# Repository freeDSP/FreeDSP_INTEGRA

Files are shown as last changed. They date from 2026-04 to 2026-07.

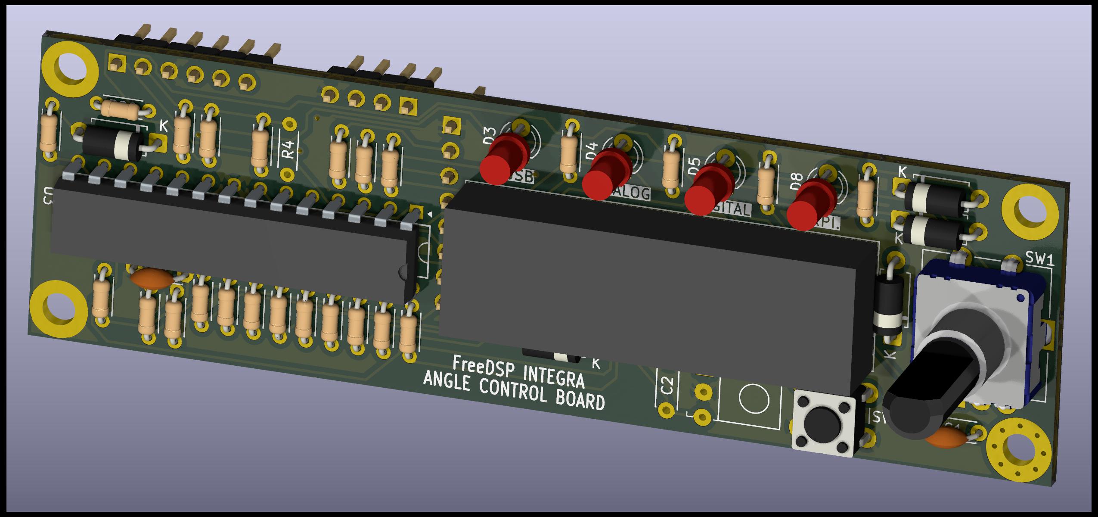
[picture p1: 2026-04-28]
KiCAD_Files/FreeDSP_INTEGRA_PANELBOARD/Picture/FreeDSP_INTEGRA_PANEL_PCB_Front.jpg

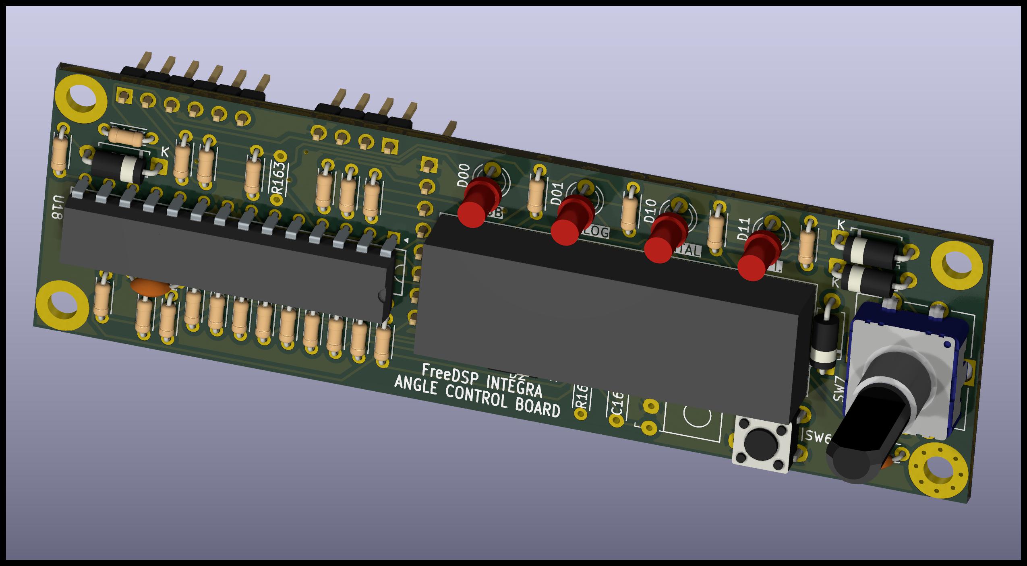
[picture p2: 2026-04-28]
KiCAD_Files/FreeDSP_INTEGRA_PANELBOARD/Picture/FreeDSP_INTEGRA_PANEL_PCB_Parse.jpg

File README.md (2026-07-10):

# FreeDSP_INTEGRA

An integrated four-channel 2.1MHz switching Class-D Amplifier embedded with an ADAU1466/1452 DSP processor.

Details are stated in the [wiki page](https://github.com/freeDSP/FreeDSP_INTEGRA/wiki)  

Project [Web page (Japanese)](https://cyberpithilo.web.fc2.com/audio/FreeDSP_INTEGRA/index.html)
  
DIY Audio [Forum Thread](https://www.diyaudio.com/community/threads/freedsp-integra.420623) 

# Variations  
## INTEGRA-QUAD BALANCED XLR INPUT VERSION 
INTEGRA_XLR

## INTEGRA-QUAD Differential RCA-PIN INPUT VERSION
INTEGRA_RCA

## Features:

BoardDiscription  

            Double Differential High-Performance ADC Input Circuit
            Balanced-XLR Input  or Differential RCA-pin Analog Input
            Optical or Coaxial S/PDIF Input
            Amanero Combo384/YORK pico or XIAO RP2040 USB-Audio Input
            Raspberry-pi ZERO 2W Slot with control buttons
            TL-232R-3V3 USB-UART Cable Connection Pin-Header for Raspberry-pi
            AUX-ADC pin header
            Onboard two AUX-ADC Trimmer-POTs
            Optional Toggle Switch for DSP control
            External Front Panel Control PCB connectivity
            DC24V Single Power Supply

# Block Diagram
  SystemBlockDiagram

# Optional Board  
Front Panel Extension Board  


# Audio Performance 
ADC Distortion Performance  

594204503-1d5c8a78-7449-4203-bfe5-b2860b34c397

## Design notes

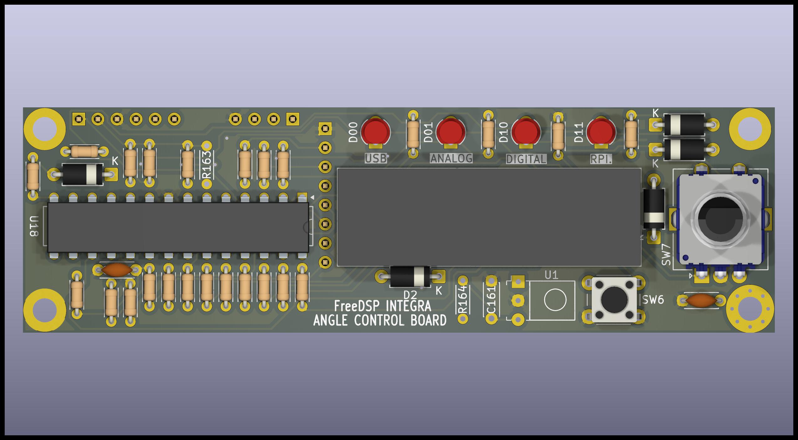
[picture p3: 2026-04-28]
KiCAD_Files/FreeDSP_INTEGRA_PANELBOARD/Picture/FreeDSP_INTEGRA_PANEL_PCB.jpg

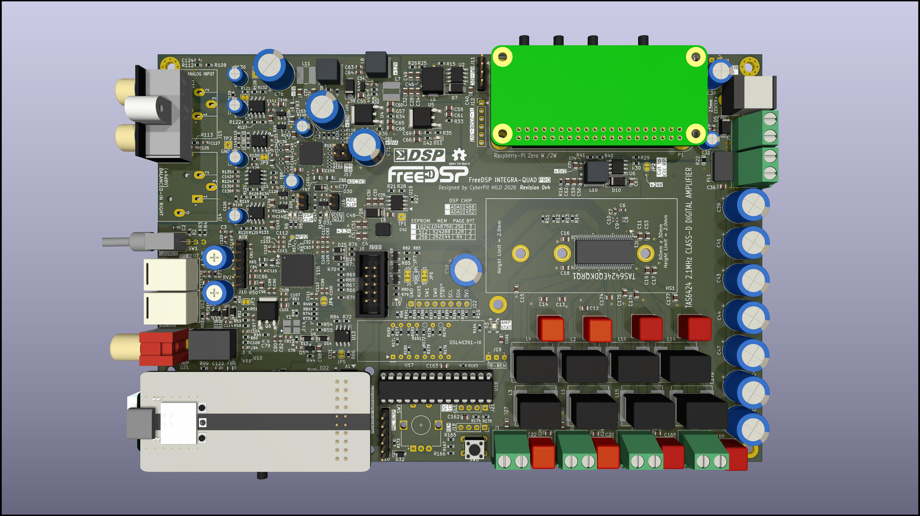
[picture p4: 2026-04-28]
KiCAD_Files/FreeDSP_INTEGRA_QUAD-PRO/Picture/FreeDSP_INTEGRA_QUAD-PRO_TopView.jpg

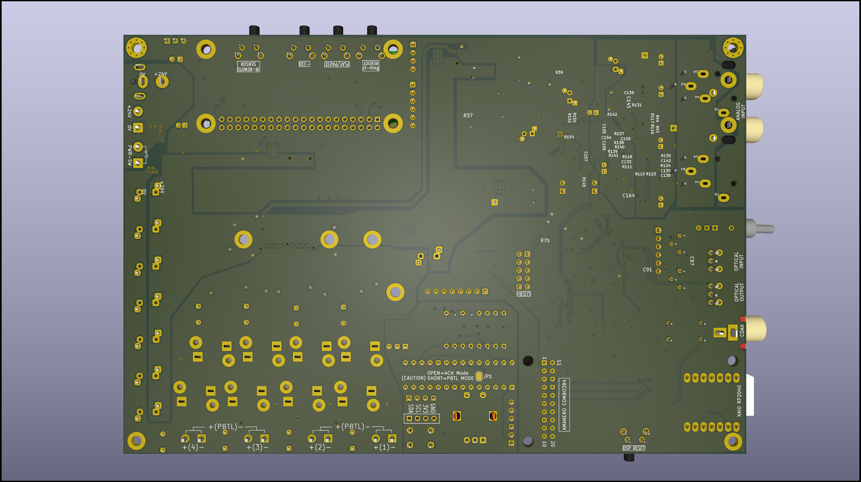
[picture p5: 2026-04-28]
KiCAD_Files/FreeDSP_INTEGRA_QUAD-PRO/Picture/FreeDSP_INTEGRA_QUAD_Bottom.jpg

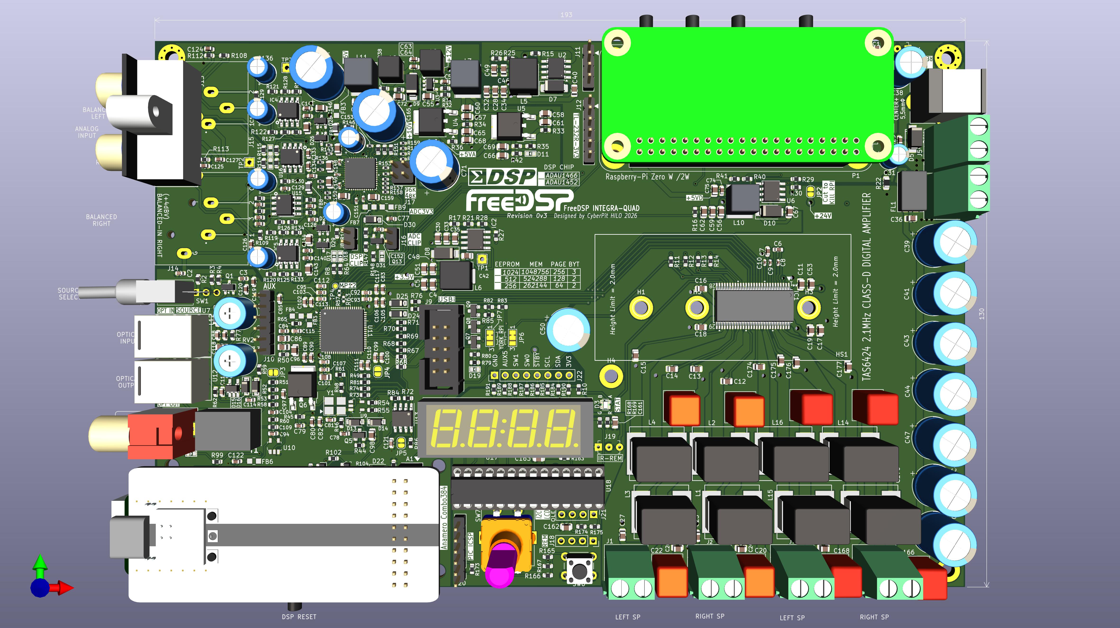
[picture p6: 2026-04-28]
KiCAD_Files/FreeDSP_INTEGRA_QUAD-PRO/Picture/FreeDSP_INTEGRA_QUAD-PRO.jpg

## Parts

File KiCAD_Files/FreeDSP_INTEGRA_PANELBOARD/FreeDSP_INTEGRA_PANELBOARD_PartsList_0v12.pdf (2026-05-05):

## FreeUSB INTEGRA Panel Board Bill of Materials

Reference | Value | JLPCB# | Footprint | Datasheet
C1 | 0.1uF/50V | HAND | Capacitor_THT:C_Disc_D4.3mm_W1.9mm_P5.00mm | MLCC 5mm pitch
C2 | 0.1uF/50V | HAND | Capacitor_THT:C_Disc_D4.3mm_W1.9mm_P5.00mm | MLCC 5mm pitch
C3 | 0.1uF/50V | HAND | Capacitor_THT:C_Disc_D4.3mm_W1.9mm_P5.00mm | MLCC 5mm pitch
C4 | 10uF/25V | NOP | Capacitor_SMD:C_0805_2012Metric | -
D1,D2,D6,D7,D9 | BAT43 1S4 | HAND | Diode_THT:D_A-405_P7.62mm_Horizontal | https://akizukidenshi.com/catalog/g/g113907/https://akizukidenshi.com/catalog/g/g116384/
D3,D4,D5,D8 | LED_YELLOW | | LED_THT:LED_D3.0mm_FlatTop | https://akizukidenshi.com/catalog/g/g111639/
HM1 | MountingHole_Pad_via | - | MountingHole:MountingHole_3.2mm_M3_ISO7380_Pad_TopBottom | ~
J1 | Conn_01x04 | NOP | Connector_PinHeader_2.54mm:PinHeader_1x04_P2.54mm_Vertical | https://akizukidenshi.com/catalog/g/g100167/
J2 | Header_01x06 | HAND | Connector_PinHeader_2.54mm:PinHeader_1x06_P2.54mm_Vertical
J3 | Conn_01x08 | HAND | Connector_PinHeader_2.54mm:PinHeader_1x08_P2.54mm_Vertical
MH1,MH2 | MountingHole | - | MountingHole:MountingHole_3.2mm_M3_DIN965_Pad_TopBottom | M3 Screw & 10mm Spacer
MH3 | M3 | - | MountingHole:MountingHole_3.2mm_M3_Pad_Via | M3 Screw & 10mm Spacer
R1,R8 | 1k | HAND | Resistor_THT:R_Axial_DIN0204_L3.6mm_D1.6mm_P5.08mm_Horizontal | Through-hole Lead Type Carbon Resistor 1/6W (5mm pitch)
R2,R3 | 470R | HAND | Resistor_THT:R_Axial_DIN0204_L3.6mm_D1.6mm_P5.08mm_Horizontal | Through-hole Lead Type Carbon Resistor 1/6W (5mm pitch)
R4 | 22k | NOP | Resistor_THT:R_Axial_DIN0204_L3.6mm_D1.6mm_P5.08mm_Horizontal | Through-hole Lead Type Carbon Resistor 1/6W (5mm pitch)
R5,R6,R7,R19,R20,R21 | 10k | HAND | Resistor_THT:R_Axial_DIN0204_L3.6mm_D1.6mm_P5.08mm_Horizontal | Through-hole Lead Type Carbon Resistor 1/6W (5mm pitch)
R9,R10,R11,R12,R13,R14,R15,R16,R22,R23,R24,R25 | 47R | HAND | Resistor_THT:R_Axial_DIN0204_L3.6mm_D1.6mm_P5.08mm_Horizontal | Through-hole Lead Type Carbon Resistor 1/6W (5mm pitch)
R17,R18 | 0R | HAND | Resistor_THT:R_Axial_DIN0204_L3.6mm_D1.6mm_P5.08mm_Horizontal | JUMPER
SW1 | EN11-HSB1AF15 | HAND | Myfootprints:RotaryEncoder_TT-Ele_EN11-HSB1AF15 | https://akizukidenshi.com/catalog/g/g106357/https://ja.aliexpress.com/item/1005012129021462.html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.

4d053lvQ3lvQ8i&gpsid=pcDetailTopMoreOtherSeller&scm=1007.40050.354490.0&scm_id=1007.40050.354490.0&scmurl=1007.40050.354490.0&pvid=e0b7cc45-f1b5-4d73-a206-cf6449d124c2&_t=gpsid%3ApcDetailTopMoreOtherSeller%2Cscm-url%3A1007.40050.354490.0%2Cpvid%3Ae0b7cc45-f1b5-4d73-a206-
cf6449d124c2%2Ctpp_buckets%3A668%232846%238116%232002&pdp_ext_f=%7B%22order%22%3A%2 2-
1%22%2C%22spu_best_type%22%3A%22price%22%2C%22eval%22%3A%221%22%2C%22sceneId%22 %3A%2230050%22%2C%22fromPage%22%3A%22recommend%22%7D&pdp_npi=6%40dis%21JPY%2110 09%21181%21%21%2143.04%217.75%21%402101529317777844403287573ea9cd%2112000057600170 808%21rec%21JP%21230125749%21XZ%211%210%21n_tag%3A-29919%3Bd%3A29f7f230%3Bm03_new_user%3A-29895&utparamurl=scene%3ApcDetailTopMoreOtherSeller%7Cquery_from%3A%7Cx_object_id%3A1005012129021462%7 C_p_origin_prod%3A (https://akizukidenshi.com/catalog/g/g106357/https:/ja.aliexpress.com/item/1005012129021462.html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)
SW2 | SW_PUSH | HAND | Button_Switch_THT:SW_PUSH_6mm_H4.3mm | https://akizukidenshi.com/catalog/g/g117166/
U1 | OSRB38C9AA | NOP | digikey-footprints:IR_Receiver_TSOP38238 | NOPOP, Not Supported
U2 | OSL40391-IX | HAND | Display_7Segment:LTC-4627Jx (Anode Common) | https://akizukidenshi.com/catalog/g/g109968/http://optoelectronics.liteon.com/upload/download/DS30-2001-093/LTC-4627JD.pdf
U3 | PIC16F1938-I/SP | HAND | Myfootprints:PIC16F1938-X&slash_SP_MCH(Socket) | PIC16F1938-I/SP
W1 | 8P Female-Female Cable | - | Jumper Cable | https://akizukidenshi.com/catalog/g/g115868/

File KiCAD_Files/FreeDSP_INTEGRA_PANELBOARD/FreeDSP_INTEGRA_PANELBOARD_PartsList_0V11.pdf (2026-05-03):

## FreeUSB INTEGRA Panel Board Bill of Materials

Reference | Value | JLPCB# | Footprint | Datasheet
C1 | 0.1uF/50V | C14663 | Capacitor_THT:C_Disc_D4.3mm_W1.9mm_P5.00mm | ~
C2 | 0.1uF/50V | C28233 | Capacitor_THT:C_Disc_D4.3mm_W1.9mm_P5.00mm | ~
C3 | 0.1uF/50V | C28233 | Capacitor_THT:C_Disc_D4.3mm_W1.9mm_P5.00mm | ~
C4 | 10uF/25V | C45783 | Capacitor_SMD:C_0805_2012Metric | ~
D1,D2,D6,D7,D9 | BAT43 | C81598 | Diode_THT:D_A-405_P7.62mm_Horizontal | https://akizukidenshi.com/catalog/g/g113907/
D3,D4,D5,D8 | LED_RED | | LED_THT:LED_D3.0mm_FlatTop | https://akizukidenshi.com/catalog/g/g111577/
HM1 | MountingHole_Pad_via | - | MountingHole:MountingHole_3.2mm_M3_ISO7380_Pad_TopBottom | ~
J1 | Conn_01x04 | HAND | Connector_PinHeader_2.54mm:PinHeader_1x04_P2.54mm_Vertical | https://akizukidenshi.com/catalog/g/g100167/
J2 | Header_01x06 | HAND | Connector_PinHeader_2.54mm:PinHeader_1x06_P2.54mm_Vertical
J3 | Conn_01x08 | HAND | Connector_PinHeader_2.54mm:PinHeader_1x08_P2.54mm_Vertical
MH1,MH2 | MountingHole | - | MountingHole:MountingHole_3.2mm_M3_DIN965_Pad_TopBottom | ~
MH3 | M3 | - | MountingHole:MountingHole_3.2mm_M3_Pad_Via | ~
R1,R2,R3,R8 | 390R,430R | | Resistor_THT:R_Axial_DIN0204_L3.6mm_D1.6mm_P5.08mm_Horizontal | Through-hole Lead Type Carbon Resistor 1/4W
R4 | 22k | C31850 | Resistor_THT:R_Axial_DIN0204_L3.6mm_D1.6mm_P5.08mm_Horizontal | Through-hole Lead Type Carbon Resistor 1/4W
R5,R6,R7,R19,R20,R21 | 10k | C25804 | Resistor_THT:R_Axial_DIN0204_L3.6mm_D1.6mm_P5.08mm_Horizontal | Through-hole Lead Type Carbon Resistor 1/4W
R9,R10,R11,R12,R13,R14,R15,R16 | 75R | C4275 | Resistor_THT:R_Axial_DIN0204_L3.6mm_D1.6mm_P5.08mm_Horizontal | Through-hole Lead Type Carbon Resistor 1/4W
R17,R18 | 0R | C21189 | Resistor_THT:R_Axial_DIN0204_L3.6mm_D1.6mm_P5.08mm_Horizontal | Through-hole Lead Type Carbon Resistor 1/4W
R22,R23,R24,R25 | 33R | C23140 | Resistor_THT:R_Axial_DIN0204_L3.6mm_D1.6mm_P5.08mm_Horizontal | Through-hole Lead Type Carbon Resistor 1/4W
SW1 | EN11-HSB1AF15 | HAND | Myfootprints:RotaryEncoder_TT-Ele_EN11-HSB1AF15 | https://akizukidenshi.com/catalog/g/g106357/https://ja.aliexpress.com/item/1005012129021462.html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.

2.4d053lvQ3lvQ8i&gpsid=pcDetailTopMoreOtherSeller&scm=1007.40050.354490.0&scm_id=1007.40050.354490.0&scmurl=1007.40050.354490.0&pvid=e0b7cc45-f1b5-4d73-a206-cf6449d124c2&_t=gpsid%3ApcDetailTopMoreOtherSeller%2Cscm-url%3A1007.40050.354490.0%2Cpvid%3Ae0b7cc45-f1b5-
SW2 | SW_PUSH | HAND | Button_Switch_THT:SW_PUSH_6mm_H4.3mm | https://akizukidenshi.com/catalog/g/g117166/
U1 | OSRB38C9AA | NOP | digikey-footprints:IR_Receiver_TSOP38238 | NOPOP, Not Supported
U2 | OSL40391-IX | HAND | Display_7Segment:LTC-4627Jx | http://optoelectronics.liteon.com/upload/download/DS30-2001-093/LTC-4627JD.pdfhttps://akizukidenshi.com/catalog/g/g109966/https://akizukidenshi.com/catalog/g/g109968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
U3 | PIC16F1938-I/SP | HAND | Myfootprints:PIC16F1938-X&slash_SP_MCH(Socket) | PIC16F1938-I/SP
W1 | 8P Female-Female Cable | - | Jumper Cable | https://akizukidenshi.com/catalog/g/g115868/

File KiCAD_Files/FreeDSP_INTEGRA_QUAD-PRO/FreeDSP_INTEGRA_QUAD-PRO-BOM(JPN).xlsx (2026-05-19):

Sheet: FreeDSP_INTEGRA_QUAD-PRO
Comment | Designator | Footprint | LCSC Part #（optional）
TPS5430DDAR | U2,U6,U19 | Package_SO:TI_SO-PowerPAD-8_ThermalVias | C9864
SDV1608E5R5C180NPTF | RV3,RV4 | OPL_Capacitor:C0603 | C98320
SWPA6028S560MT | L8 | Inductor_SMD:L_Taiyo-Yuden_NR-60xx_HandSoldering | C96944
10uF | C85,C87,C128,C133,C138,C142,C158 | Capacitor_SMD:C_0603_1608Metric | C96446
OPA1612AIDR | U15,U16 | Myfootprints:SOIC127P600X175-8N | C94590
OPA1632DR | IC4,IC5 | Myfootprints:SOIC127P600X175-8N | C86715
B5819W SL | D6,D13,D14,D15,D16 | Diode_SMD:D_SOD-123 | C8598
2N7002 | Q4,Q5,Q8,Q9,Q12,Q13 | Package_TO_SOT_SMD:SOT-23 | C8545
MMBT5401 | Q2,Q3 | Package_TO_SOT_SMD:SOT-23 | C8326
1N4148W | D1,D2,D4,D20,D22,D23,D24,D25,D30,D32 | Diode_SMD:D_SOD-123 | C81598
LM317AG-TN3-R | U4,U5 | Package_TO_SOT_SMD:TO-252-2 | C77880
1nF/50V(C0G) | C24,C25,C26,C27,C86,C170,C171,C172,C173 | Capacitor_SMD:C_0805_2012Metric | C76625
BAT54A | D26,D27 | Package_TO_SOT_SMD:SOT-23 | C7502690
74LVC1G86 | U8 | Package_TO_SOT_SMD:SOT-23-5_HandSoldering | C73458
ADAU1466 | U11 | Myfootprints:LFCSP-72-1EP_10x10mm_P0.5mm_EP5.3x5.3mmL_HandSolder | C654414
SWPA6045S101MT | L7,L11 | Inductor_SMD:L_Ferrocore_DLG-0504 | C60633
10nF | C54,C81 | Capacitor_SMD:C_0603_1608Metric | C57112
1uF | C8,C9,C10,C157 | Capacitor_SMD:C_0402_1005Metric | C52923
FXL1350-100-M | L1,L2,L3,L4,L13,L14,L15,L16 | MyLibrary:7G14C47 | C526017
TAS6424EQDKQRQ1 | IC1 | Myfootprints:TAS6424QDKQ56_TEX-L | C4991409
2.2pF | C109 | Resistor_SMD:R_0603_1608Metric | C46219
22uF/6.3V | C49,C51,C75,C163 | Capacitor_SMD:C_0805_2012Metric | C45783
10uF/50V | C5,C16,C19,C28,C30,C55,C56,C57,C58,C72,C73,C98,C101,C118,C159 | Capacitor_SMD:C_0805_2012Metric | C440198
74LVC1G04 | U9 | digikey-footprints:SOT-753 | C434067
75R | R176,R177,R178,R179,R180,R181,R182,R183 | Resistor_SMD:R_0603_1608Metric | C4275
33k | R16 | Resistor_SMD:R_0603_1608Metric | C4216
2.2k | R4,R8,R13,R14,R46,R64,R75,R76,R87,R90 | Resistor_SMD:R_0603_1608Metric | C4190
1.8K | R94 | Resistor_SMD:R_0603_1608Metric | C4177
2.2uF/50V | C11,C12,C13,C14,C15,C174,C175,C176,C177 | Capacitor_SMD:C_0805_2012Metric | C377773
BAT54C | D28,D29 | Package_TO_SOT_SMD:SOT-23 | C37704
SDFL2012T220KTF | L12 | Inductor_SMD:L_0805_2012Metric_Pad1.05x1.20mm_HandSolder | C32375
22k | R23,R163 | Resistor_SMD:R_0603_1608Metric | C31850
0.1uF | C151,C154,C155,C156 | Capacitor_SMD:C_0402_1005Metric | C307331
74LVC1G04M5/TR | U10 | digikey-footprints:SOT-753 | C3007927
MACM9070-701 | FL1 | Myfootprints:ACM9070 | C2981417
1uF/50V | C32,C33,C59,C68,C69 | Capacitor_SMD:C_0805_2012Metric | C28323
OT322524.576MJBA4S | Y1 | Crystals:Crystal_SMD_TXC_7M-4pin_3.2x2.5mm_HandSoldering | C2831388
0.1uF/100V | C4,C17,C18,C34,C35,C36,C40,C42,C46,C48,C53,C60,C61,C62,C65,C66,C67,C161,C162 | Capacitor_SMD:C_0805_2012Metric | C28233
AK5574EN | IC3 | QFN48_AKM | C2651665
LED_ABGR | D3 | MyLED:LED_0603_ABGR | C264517
47k | R116,R117 | Resistor_SMD:R_0603_1608Metric | C25819
10k | R7,R15,R24,R29,R39,R40,R79,R82,R83,R84,R85,R86,R103,R165,R166,R167,R173,R174,R175 | Resistor_SMD:R_0603_1608Metric | C25804
100k | R19,R53,R104,R110,R111,R123,R124 | Resistor_SMD:R_0603_1608Metric | C25803
10k | R149,R153,R154,R160,R161,R162 | Resistor_SMD:R_0402_1005Metric | C25744
47R | R155,R156,R157,R158 | Resistor_SMD:R_0402_1005Metric | C25118
10R | R136,R137,R138,R139,R140,R141,R142,R143 | Resistor_SMD:R_0402_1005Metric | C25077
22R | R144,R146 | Resistor_SMD:R_0603_1608Metric | C23345
680R | R31 | Resistor_SMD:R_0603_1608Metric | C23228
510R | R125,R126,R127,R128 | Resistor_SMD:R_0603_1608Metric | C23193
5.6k | R27 | Resistor_SMD:R_0603_1608Metric | C23189
47R | R1,R6,R9,R59,R61,R65,R88,R93,R100,R101,R164 | Resistor_SMD:R_0603_1608Metric | C23182
470K | R18 | Resistor_SMD:R_0603_1608Metric | C23178
4.3k | R2,R50 | Resistor_SMD:R_0603_1608Metric | C23159
33R | R48,R51,R54,R55,R56,R66,R67,R68,R69,R70,R71,R72,R73,R74,R96,R97,R98,R131,R132,R133,R134,R170,R171,R172 | Resistor_SMD:R_0603_1608Metric | C23140
330R | R10,R32,R33 | Resistor_SMD:R_0603_1608Metric | C23138
3.24k | R28,R41 | Resistor_SMD:R_0603_1608Metric | C22994
3.3k | R12,R21,R26,R30,R42,R43,R95,R107 | Resistor_SMD:R_0603_1608Metric | C22978
29.4k | R25,R38 | Resistor_SMD:R_0603_1608Metric | C22974
LED_BLU | D12 | LED_SMD:LED_0603_1608Metric_Pad1.05x0.95mm_HandSolder | C2297
270R | R129,R130 | Resistor_SMD:R_0603_1608Metric | C22966
220R | R147,R148 | Resistor_SMD:R_0603_1608Metric | C22962
LED_YELLOW | D19 | LED_SMD:LED_0603_1608Metric_Pad1.05x0.95mm_HandSolder | C2296
1MEG | R20,R44,R105,R106,R145 | Resistor_SMD:R_0603_1608Metric | C22935
LED_WHITE | D21 | LED_SMD:LED_0603_1608Metric_Pad1.05x0.95mm_HandSolder | C2290
LED_RED | D18,D31 | LED_SMD:LED_0603_1608Metric_Pad1.05x0.95mm_HandSolder | C2286
10R | R37,R112,R113,R114,R115 | Resistor_SMD:R_0603_1608Metric | C22859
150R | R36,R52,R58,R81 | Resistor_SMD:R_0603_1608Metric | C22808
100R | R35,R77,R118,R135 | Resistor_SMD:R_0603_1608Metric | C22775
1.2k | R60 | Resistor_SMD:R_0603_1608Metric | C22765
1.1k | R3,R119,R120,R121,R122 | Resistor_SMD:R_0603_1608Metric | C22764
SS54(5A) | D5,D7,D8,D9,D10 | Diode_SMD:D_SMA | C22452
25AA1024(512) | U13 | Package_SO:SOIC-8_3.9x4.9mm_P1.27mm | C219767
1k | R11,R34,R45,R49,R62,R80,R99 | Resistor_SMD:R_0603_1608Metric | C21190
0R | R47,R78,R108,R109,R150,R184,R185,R186,R187,R188,R189,R190,R191 | Resistor_SMD:R_0603_1608Metric | C21189
AO3400A | Q11 | Package_TO_SOT_SMD:SOT-23 | C20917
FXL0420-4R7-M | L6 | Inductor_SMD:L_TechFuse_SL0420 | C207830
LM2611AMFX | U3 | Package_TO_SOT_SMD:SOT-23-5 | C2072505
22pF(C0G) | C143,C144,C145,C146 | Capacitor_SMD:C_0805_2012Metric | C1804
0R | R22 | Resistor_SMD:R_0805_2012Metric_Pad1.20x1.40mm_HandSolder | C17477
4700pF | C91 | Capacitor_SMD:C_0805_2012Metric | C1744
1500pF(C0G) | C148,C149,C150,C160 | Capacitor_SMD:C_0805_2012Metric | C1717
150pF | C96 | Capacitor_SMD:C_0805_2012Metric | C1716
1uF | C6,C7,C63,C64,C77,C83,C89,C92,C95,C99,C102,C105,C107,C110,C112 | Capacitor_SMD:C_0603_1608Metric | C15849
AO3401A | Q7 | Package_TO_SOT_SMD:SOT-23 | C15127
SMMS0650-220M | L10 | Inductor_SMD:L_Taiyo-Yuden_NR-60xx_HandSoldering | C149586
SMMS0650-150M | L5 | Inductor_SMD:L_Chilisin_BMRB00060650 | C149585
0.1uF/50V | C1,C2,C3,C29,C37,C74,C78,C80,C82,C84,C88,C90,C93,C94,C97,C100,C103,C106,C108,C111,C113,C114,C115,C116,C117,C119,C120,C121,C122,C123,C124,C125,C126,C127,C129,C130,C134,C135,C139,C140,C141,C152,C164 | Capacitor_SMD:C_0603_1608Metric | C14663
MJD45H11T4 | Q6 | Package_TO_SOT_SMD:TO-252-2 | C138783
SMNR5040-220MT | L9 | Inductor_SMD:L_Taiyo-Yuden_NR-60xx_HandSoldering | C128694
LED_GRN | D11,D17 | LED_SMD:LED_0603_1608Metric_Pad1.05x0.95mm_HandSolder | C12624
GZ2012D601TF | FB1,FB2,FB3,FB4,FB5,FB6,FB7,FB8,FB9 | Inductor_SMD:L_0805_2012Metric | C1017

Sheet: HandMount
FreeDSP NTEGRA QUAD STD Handmount parts List
Comment | Designator | Footprint | URL
10uF/16V | C131,C132,C136,C137 | Capacitor_THT:CP_Radial_D5.0mm_P2.00mm
100uF/16V_OS | C147,C153 | Capacitor_THT:CP_Radial_D5.0mm_P2.50mm
330uF/16V | C165 | Capacitor_THT:CP_Radial_D10.0mm_P2.50mm_P5.00mm
1.0uF/50V | C20,C21,C22,C23,C166,C167,C168,C169 | Capacitor_THT:C_Rect_L7.2mm_W7.2mm_P5.00mm_FKS2_FKP2_MKS2_MKP2
22uF/16V | C31 | Capacitor_THT:CP_Radial_D5.0mm_P2.00mm
220uF/25V | C38 | Capacitor_THT:CP_Radial_D7.5mm_P2.50mm
470uF/25V_OS | C39,C41,C43,C44,C45,C47,C50,C52 | Capacitor_THT:CP_Radial_D10.0mm_P5.00mm_P7.50mm
220uF/6.3V | C71,C76 | Capacitor_THT:CP_Radial_D10.0mm_P2.50mm_P5.00mm
Heatsink | HS1 | MyLibrary:HeatSink_30P61A
Screw_Terminal_01x02 | J1,J2,J4,J5,J7,J23 | TerminalBlock_Phoenix:TerminalBlock_Phoenix_MKDS-1,5-2-5.08_1x02_P5.08mm_Horizontal
Conn_01x05,Header_01x06 | J10,J20 | Connector_PinHeader_2.54mm:PinHeader_1x06_P2.54mm_Vertical
Header_01x06 | J12 | Connector_PinHeader_2.54mm:PinHeader_1x06_P2.54mm_Vertical
MJ518A/RCJ2123 | J13 | MyJacks:MJ-518A | https://ja.aliexpress.com/item/1005001485859972.html
Molex_MPJ-8004-3P | J14,J15 | Myfootprints:MPJ-8004-3P
Conn_01x02 | J16 | Connector_PinHeader_2.54mm:PinHeader_2x01_P2.54mm_Vertical
PinHeader_02x02 | J17 | Connector_PinHeader_2.54mm:PinHeader_2x02_P2.54mm_Vertical
Conn_01x04 | J21 | Connector_PinHeader_2.54mm:PinHeader_1x04_P2.54mm_Vertical
Conn_01x08 | J22 | Connector_PinHeader_2.54mm:PinHeader_1x08_P2.54mm_Vertical
Barrel_Jack_2DC-G213-D42 | J3 | MyLibrary:BarrelJack_2DC-G213-D42 | https://ja.aliexpress.com/item/1005008919807552.html?curPageLogUid=YvIByTZzOHTp
Conn_Coaxial | J6 | MyJacks:RJ-2410N | https://ja.aliexpress.com/item/1005004552064256.html?curPageLogUid=uJ8MpVJHwzY0
Conn_01x02 | J8 | Connector_PinHeader_2.54mm:PinHeader_1x02_P2.54mm_Vertical
IDC_2x5 | J9 | Connector_IDC:IDC-Header_2x05_P2.54mm_Vertical
Conn_02x20_Odd_Even | P1 | Module:Raspberry_Pi_Zero_Socketed_THT_FaceDown_MountingHoles
B10K | RV1,RV2 | MyLibrary:Potentiometer_Trimmer_Bourns_3339P_Horizontal
SW_SPDT_MSM | SW1 | Myfootprints:2MS1T1B4M7QES
DSP_RES,SW_Push | SW2,SW3,SW4,SW5,SW8 | Button_Switch_THT:SW_Tactile_SPST_Angled_PTS645Vx83-2LFS | https://ja.aliexpress.com/item/1005008542183827.html?curPageLogUid=pKZ7YVxYECf6
SW_PUSH | SW6 | Button_Switch_THT:SW_PUSH_6mm_H4.3mm
EN11-HSB1AF15 | SW7 | Myfootprints:RotaryEncoder_TT-Ele_EN11-HSB1AF15 | https://ja.aliexpress.com/item/1005005983134515.html?scm_id=1007.40050.354490.0&scm-url=1007.40050.354490.0
PE-65612NL | T1 | MyLibrary:PE65612NL | https://ja.aliexpress.com/item/1005010235537178.html?curPageLogUid=5QQvObvGR2vx
PLT133-T10W | U12 | MyLibrary:PLT133-T10W | https://ja.aliexpress.com/item/1005009571325413.html?curPageLogUid=yz0TKIzTcxtk
Combo384-Combo384 | A1 | 10x2 Header Socket for Amanero Combo384 | Hi-Res Audio Interface, Alternative 16bit 48kHz choice U14 is availabel
XIAO_RP2040 | U14 | Myfootprints:XIAO_RP2040 | Alternative Choice of A1 (Limitted up to 48kHz, 16bit)
OSL40391-IX | U17 | Display_7Segment:LTC-4627Jx
PIC16F1938-I/SP | U18 | Package_DIP:DIP-28_W7.62mm
PLR135-T10 | U7 | MyLibrary:PLR135-T10 | https://ja.aliexpress.com/item/1005009545686187.html

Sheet: DNP
Comment | Designator | Footprint | LCSC Part #（optional）
MountingHole | H1,H2,H3,H4,H5,H6 | MountingHole:MountingHole_3.2mm_M3_DIN965_Pad_TopBottom | -
MountingHole_Pad_via | H7 | Mounting_Holes:MountingHole_3.2mm_M3_Pad_Via | -
Jumper_NC,SolderJumper_3_Bridged12 | JP1,JP2,JP9,JP10,JP11 | Jumper:SolderJumper-2_P1.3mm_Bridged_RoundedPad1.0x1.5mm | -
Jumper_NC | JP3,JP5 | Jumper:SolderJumper-2_P1.3mm_Bridged_RoundedPad1.0x1.5mm | -
Jumper_NO,Jumper_NO_Small | JP4,JP8 | Jumper:SolderJumper-2_P1.3mm_Open_RoundedPad1.0x1.5mm | -
SolderJumper_3_Bridged12 | JP6,JP7 | Jumper:SolderJumper-3_P1.3mm_Bridged12_Pad1.0x1.5mm_NumberLabels | -
Logo_Open_Hardware_Small | LOGO1 | LogoLibrary:LOGO_FREEDSP_600dpi | -
M3 | MH1 | MountingHole:MountingHole_3.2mm_M3_Pad_Via | -
TestPoint_GND,TestPoint_GNDA | TP1,TP2,TP3 | TestPoint:TestPoint_THTPad_2.0x2.0mm_Drill1.0mm | -
TEST_MP12 | TP4 | TestPoint:TestPoint_Pad_D1.0mm | -
XIAO_RP2040 | U14 | Myfootprints:XIAO_RP2040 | -
LOGO | Z1 | LogoLibrary:SigmaDSP-LogoSmall | -
LOGO | Z2 | LogoLibrary:AmaneroLogo | -
LOGO | Z3 | LogoLibrary:RasPiLogoSmall | -
NOP | C70,C79 | Capacitor_SMD:C_0603_1608Metric | NOP
NOP | C104 | Capacitor_SMD:C_0603_1608Metric | NOP
Header_01x04 | J11 | Connector_PinHeader_2.54mm:PinHeader_1x04_P2.54mm_Vertical | NOP
Conn_01x04 | J18 | Connector_PinSocket_2.54mm:PinSocket_1x04_P2.54mm_Vertical | NOP
OSRB38C9AA | J19 | digikey-footprints:IR_Receiver_TSOP38238 | NOP
NOP | R5,R89,R151,R152 | Resistor_SMD:R_0603_1608Metric | NOP
NOP | R57,R63 | Resistor_SMD:R_0402_1005Metric | NOP
NOP | R91,R92 | Resistor_SMD:R_0603_1608Metric | NOP
NOP | R159 | Resistor_SMD:R_0402_1005Metric | NOP
GP1UXC41QS | U1 | digikey-footprints:IR_Receiver_TSOP38238 | NOP

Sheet: HandMount (Japan)
FreeDSP NTEGRA QUAD STD Handmount parts List
Comment | Designator | Footprint | URL
22uF/16V | C131,C132,C136,C137 | Capacitor_THT:CP_Radial_D5.0mm_P2.00mm | https://akizukidenshi.com/catalog/g/g110592/
100uF/16V_OS | C147,C153 | Capacitor_THT:CP_Radial_D5.0mm_P2.50mm | https://akizukidenshi.com/catalog/g/g108290/
330uF/25V OS | C165 | Capacitor_THT:CP_Radial_D10.0mm_P2.50mm_P5.00mm | https://akizukidenshi.com/catalog/g/g108298/
1.0uF/50V FILM | C20,C21,C22,C23,C166,C167,C168,C169 | Capacitor_THT:C_Rect_L7.2mm_W7.2mm_P5.00mm_FKS2_FKP2_MKS2_MKP2 | https://akizukidenshi.com/catalog/g/g114602/
10uF/25V | C31 | Capacitor_THT:CP_Radial_D5.0mm_P2.00mm | https://akizukidenshi.com/catalog/g/g110592/
220uF/25V | C38 | Capacitor_THT:CP_Radial_D7.5mm_P2.50mm | https://akizukidenshi.com/catalog/g/g116870/
820uF/25V_OS | C39,C41,C43,C44,C45,C47,C50,C52 | Capacitor_THT:CP_Radial_D10.0mm_P5.00mm_P7.50mm | https://akizukidenshi.com/catalog/g/g116863/
220uF/6.3V OS | C71,C76 | Capacitor_THT:CP_Radial_D10.0mm_P2.50mm_P5.00mm | https://akizukidenshi.com/catalog/g/g116870/
Heatsink | HS1 | MyLibrary:HeatSink_30P61A | https://akizukidenshi.com/catalog/g/g112537/
Screw_Terminal_01x02 | J1,J2,J4,J5,J7,J23 | TerminalBlock_Phoenix:TerminalBlock_Phoenix_MKDS-1,5-2-5.08_1x02_P5.08mm_Horizontal | https://akizukidenshi.com/catalog/g/g115682/
Conn_01x05,Header_01x06 | J10,J20 | Connector_PinHeader_2.54mm:PinHeader_1x06_P2.54mm_Vertical | https://akizukidenshi.com/catalog/g/g100167/
Header_01x06 | J12 | Connector_PinHeader_2.54mm:PinHeader_1x06_P2.54mm_Vertical | https://akizukidenshi.com/catalog/g/g100167/
MJ518A/RCJ2123 | J13 | MyJacks:MJ-518A | https://ja.aliexpress.com/item/1005001485859972.html
Molex_MPJ-8004-3P | J14,J15 | Myfootprints:MPJ-8004-3P （XLR User Only) | https://akizukidenshi.com/catalog/g/g115761/
Conn_01x02 | J16 | Connector_PinHeader_2.54mm:PinHeader_2x01_P2.54mm_Vertical | https://akizukidenshi.com/catalog/g/g100167/
PinHeader_02x02 | J17 | Connector_PinHeader_2.54mm:PinHeader_2x02_P2.54mm_Vertical | https://akizukidenshi.com/catalog/g/g100167/ https://akizukidenshi.com/catalog/g/g103689/
Conn_01x04 | J21 | Connector_PinHeader_2.54mm:PinHeader_1x04_P2.54mm_Vertical | https://akizukidenshi.com/catalog/g/g100167/
Conn_01x08 | J22 | Connector_PinHeader_2.54mm:PinHeader_1x08_P2.54mm_Vertical | https://akizukidenshi.com/catalog/g/g100167/
Barrel_Jack_2DC-G213-D42 | J3 | MyLibrary:BarrelJack_2DC-G213-D42 | https://akizukidenshi.com/catalog/g/g106907/
Conn_Coaxial | J6 | MyJacks:RJ-2410N | https://akizukidenshi.com/catalog/g/g106508/
Conn_01x02 | J8 | Connector_PinHeader_2.54mm:PinHeader_1x02_P2.54mm_Vertical | https://akizukidenshi.com/catalog/g/g100167/
IDC_2x5 | J9 | Connector_IDC:IDC-Header_2x05_P2.54mm_Vertical | https://akizukidenshi.com/catalog/g/g112664/
Conn_02x20_Odd_Even | P1 | Module:Raspberry_Pi_Zero2W_Socketed_THT_FaceDown_MountingHoles | https://akizukidenshi.com/catalog/g/g100085/
B10K | RV1,RV2 | MyLibrary:Potentiometer_Trimmer_Bourns_3339P_Horizontal | https://akizukidenshi.com/catalog/g/g114906/
SW_SPDT_MSM | SW1 | Myfootprints:2MS1T1B4M7QES | https://akizukidenshi.com/catalog/g/g113796/
DSP_RES,SW_Push | SW2,SW3,SW4,SW5,SW8 | Button_Switch_THT:SW_Tactile_SPST_Angled_PTS645Vx83-2LFS | https://akizukidenshi.com/catalog/g/g107193/
SW_PUSH | SW6 | Button_Switch_THT:SW_PUSH_6mm_H4.3mm | https://akizukidenshi.com/catalog/g/g117166/
EN11-HSB1AF15 | SW7 | Myfootprints:RotaryEncoder_TT-Ele_EN11-HSB1AF15 | https://akizukidenshi.com/catalog/g/g106357/
PE-65612NL | T1 | MyLibrary:PE65612NL | https://ja.aliexpress.com/item/1005010235537178.html?curPageLogUid=5QQvObvGR2vx
PLT133-T10W | U12 | MyLibrary:PLT133-T10W | https://ja.aliexpress.com/item/1005009571325413.html?curPageLogUid=yz0TKIzTcxtk
Combo384-Combo384 | A1 | 10x2 Header Socket for Amanero Combo384 | Hi-Res Audio Interface, Alternative 16bit 48kHz choice U14 is availabel
XIAO_RP2040 | U14 | Myfootprints:XIAO_RP2040 | Alternative Choice of A1 (Limitted up to 48kHz, 16bit)
OSL40391-IX | U17 | Display_7Segment:LTC-4627Jx | https://akizukidenshi.com/catalog/g/g109970/ https://akizukidenshi.com/catalog/g/g109968/
PIC16F1938-I/SP | U18 | Package_DIP:DIP-28_W7.62mm | https://akizukidenshi.com/catalog/g/g104357/
PLR135-T10 | U7 | MyLibrary:PLR135-T10 | https://ja.aliexpress.com/item/1005009545686187.html

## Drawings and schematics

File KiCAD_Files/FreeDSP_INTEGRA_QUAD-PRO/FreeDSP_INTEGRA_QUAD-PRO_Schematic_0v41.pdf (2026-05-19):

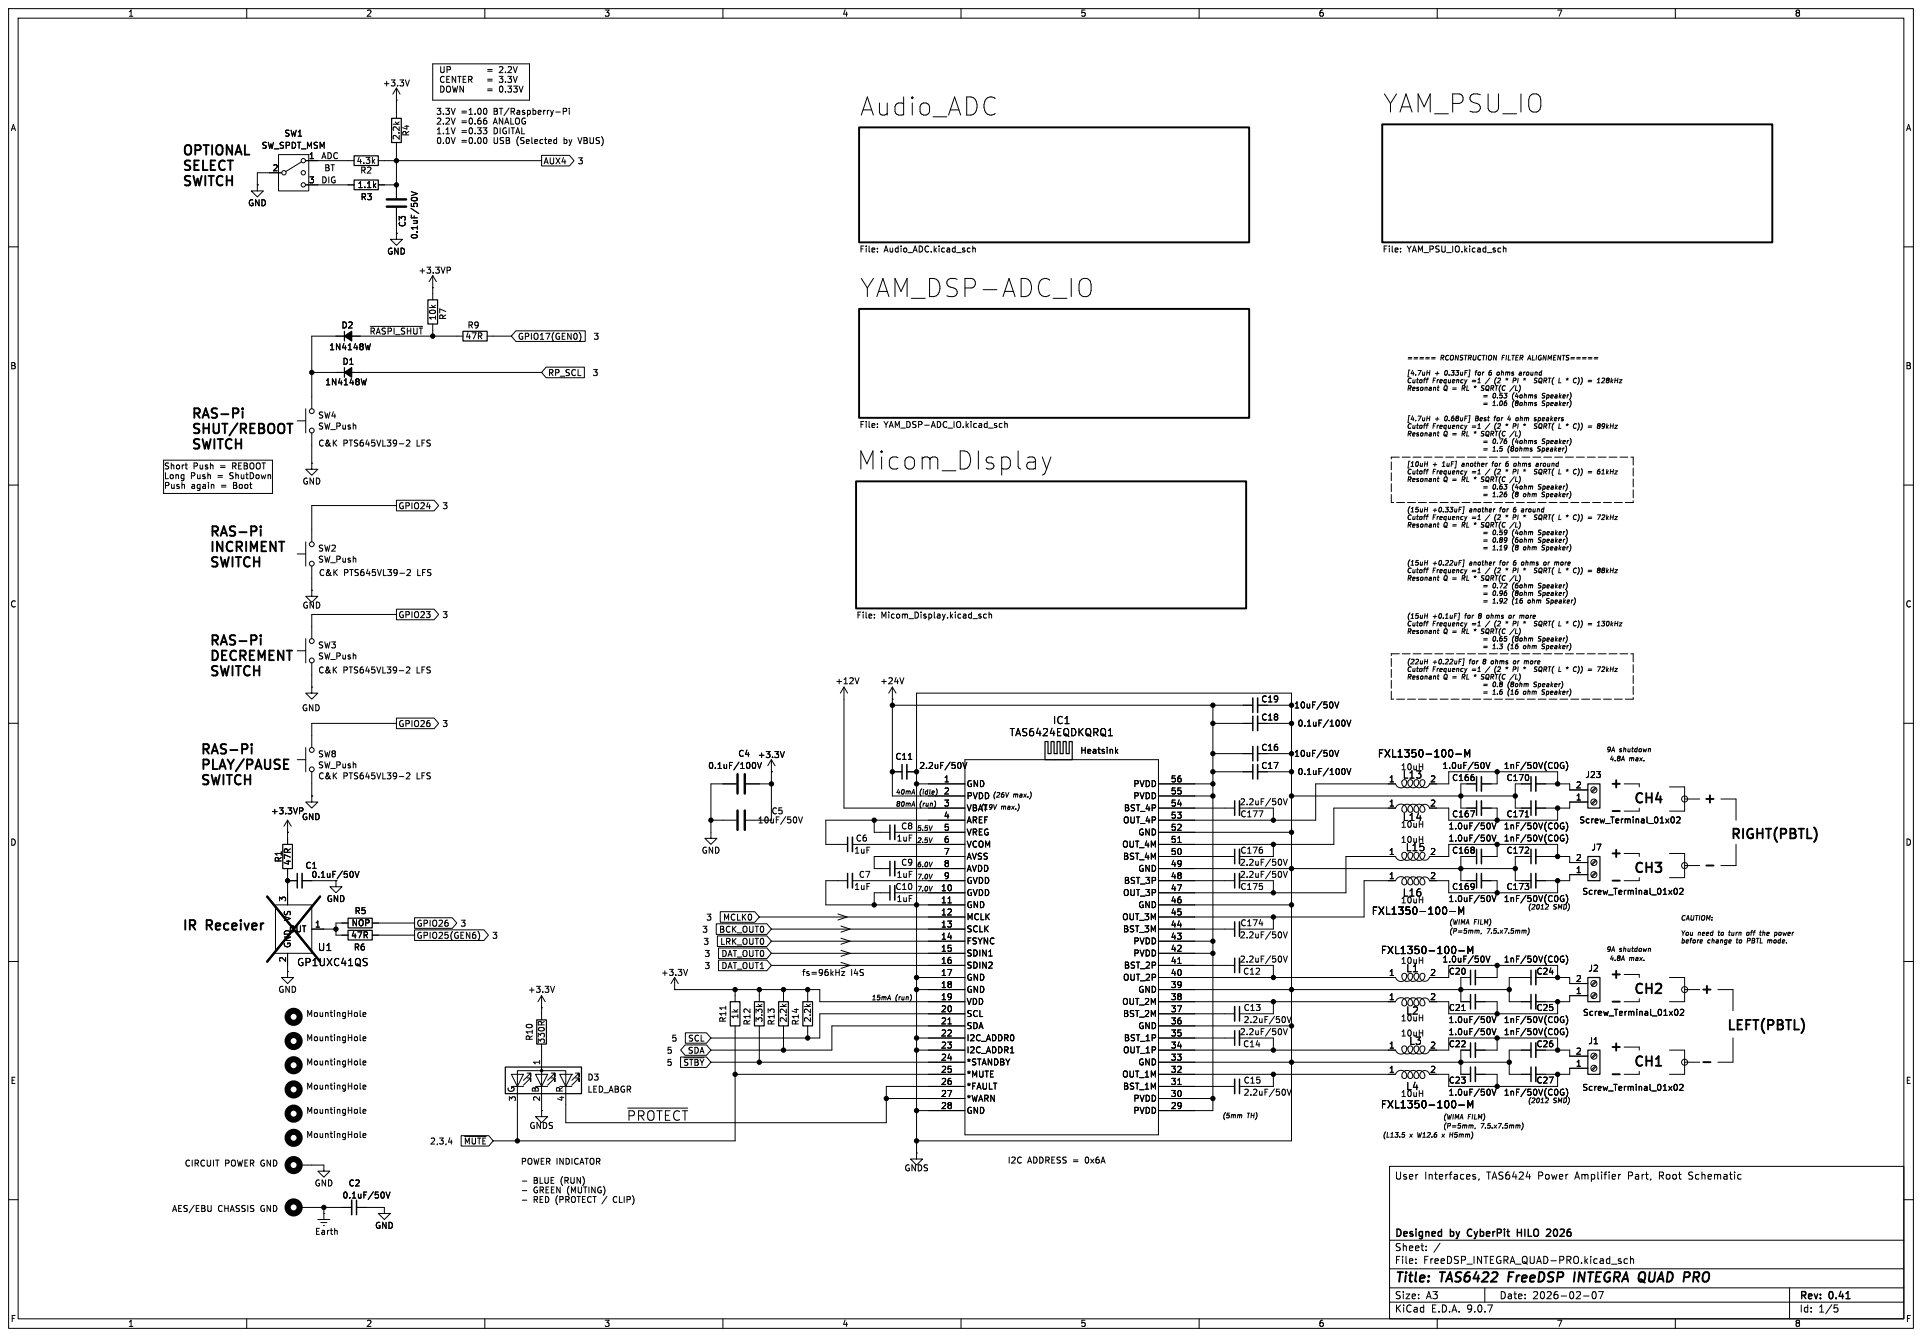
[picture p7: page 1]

BT ADC RAS-Pi
SW4 SW_PushR5 NOP MountingHole

SHUT/REBOOT
SWITCH
AES/EBU CHASSIS GND RAS-Pi
SW3 SW_Push R1 47R

Id: 1/5 Title: TAS6422 FreeDSP INTEGRA QUAD PRO

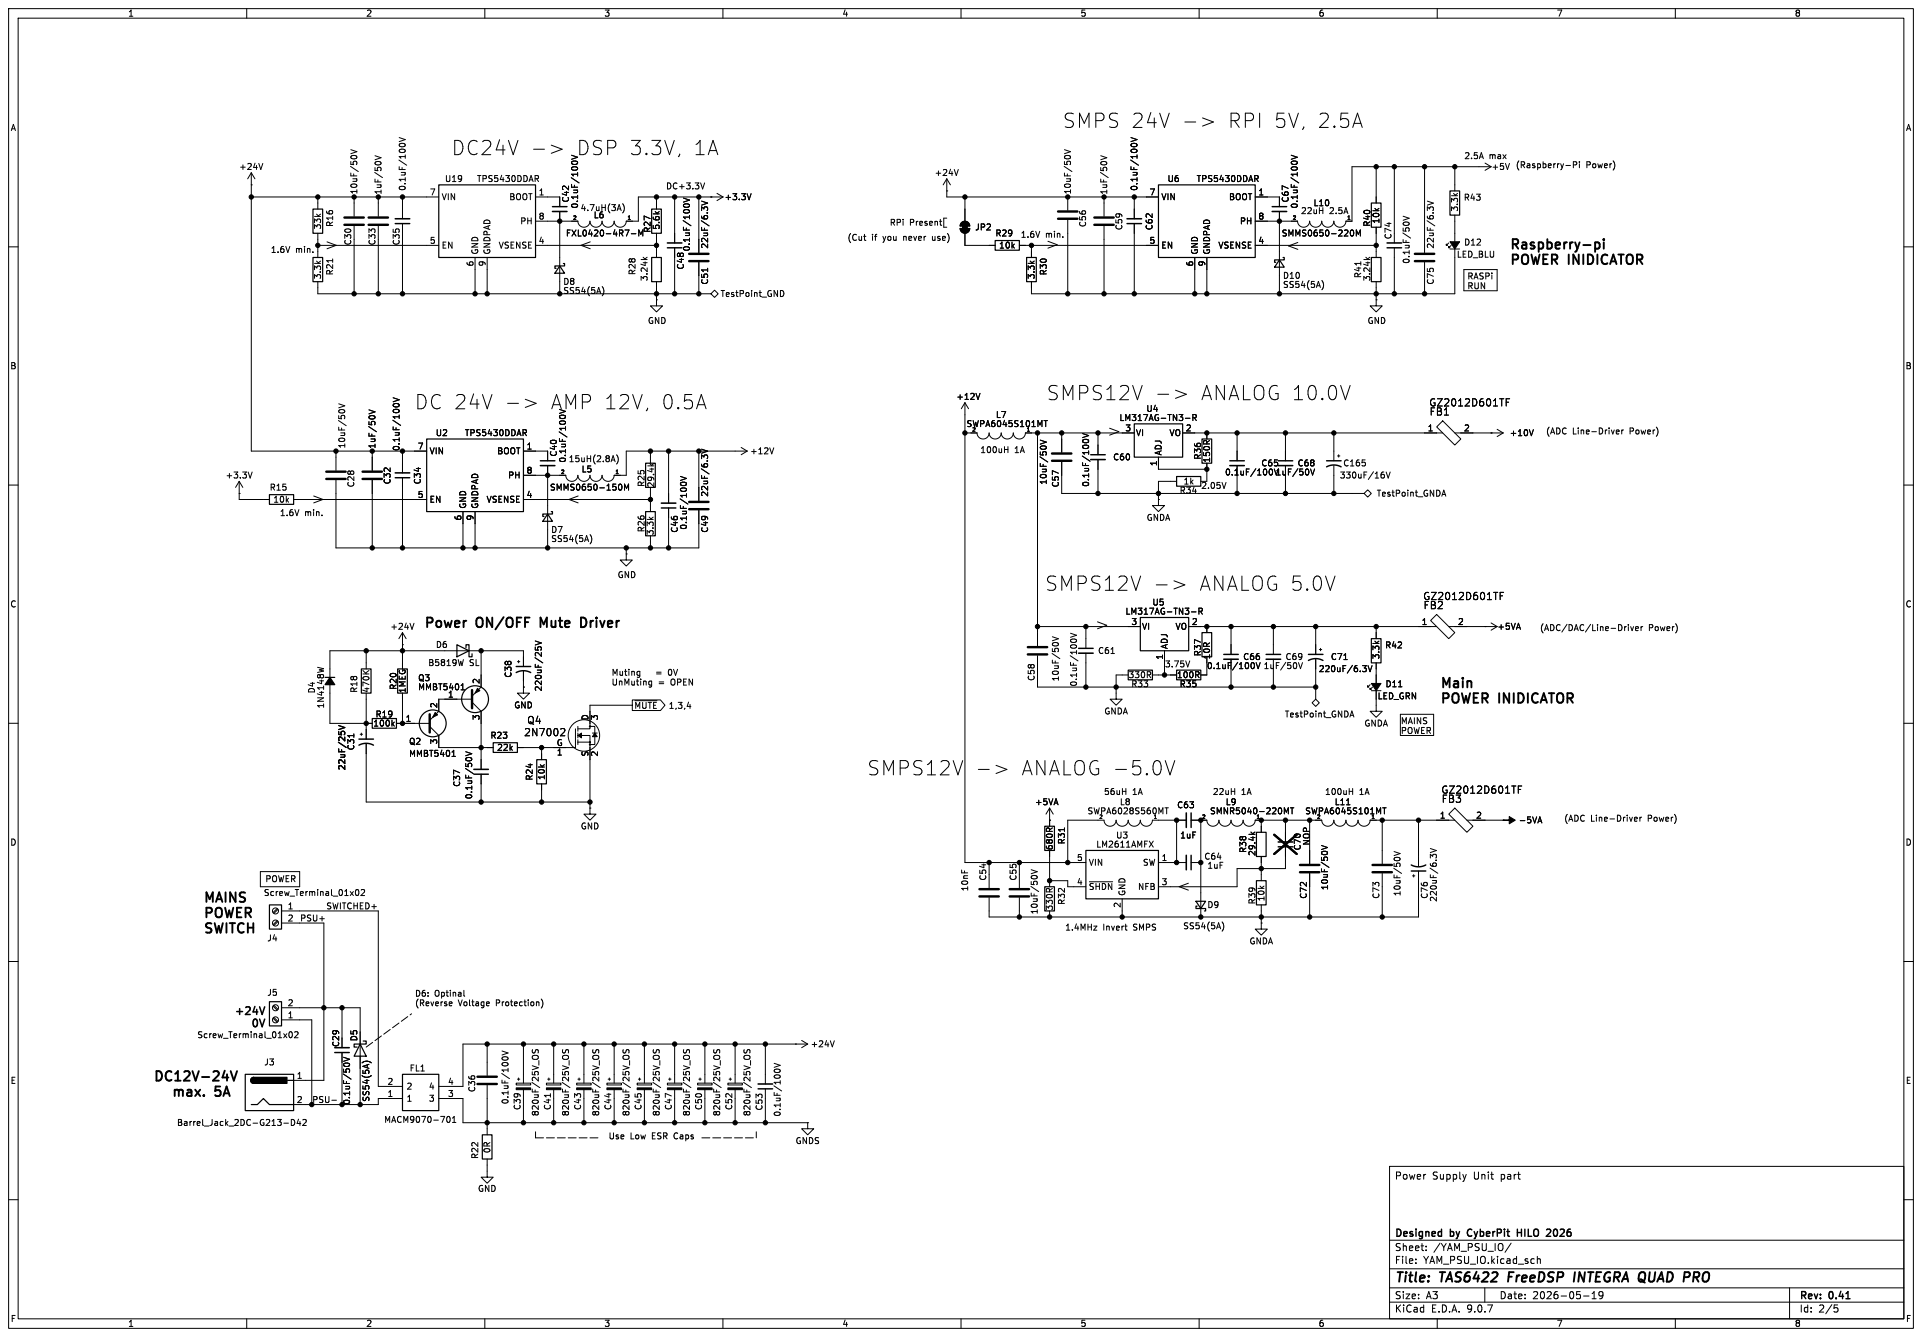
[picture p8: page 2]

DC+3.3V Power ON/OFF Mute Driver

9 BOOT 1 PH 8 VSENSE 4 U6 TPS5430DDAR C45 820uF/25V_OS C67 0.1uF/100V C47 820uF/25V_OS R40 10k D10 SS54(5A) R41 3.24k VI 3 ADJ 1 VO 2 U4

~{MUTE}1,3,4 SWITCHED+ PSU+PSU- POWER MAINS

Use Low ESR Caps

File: YAM_PSU_IO.kicad_sch Sheet: /YAM_PSU_IO/
Id: 2/5 Title: TAS6422 FreeDSP INTEGRA QUAD PRO

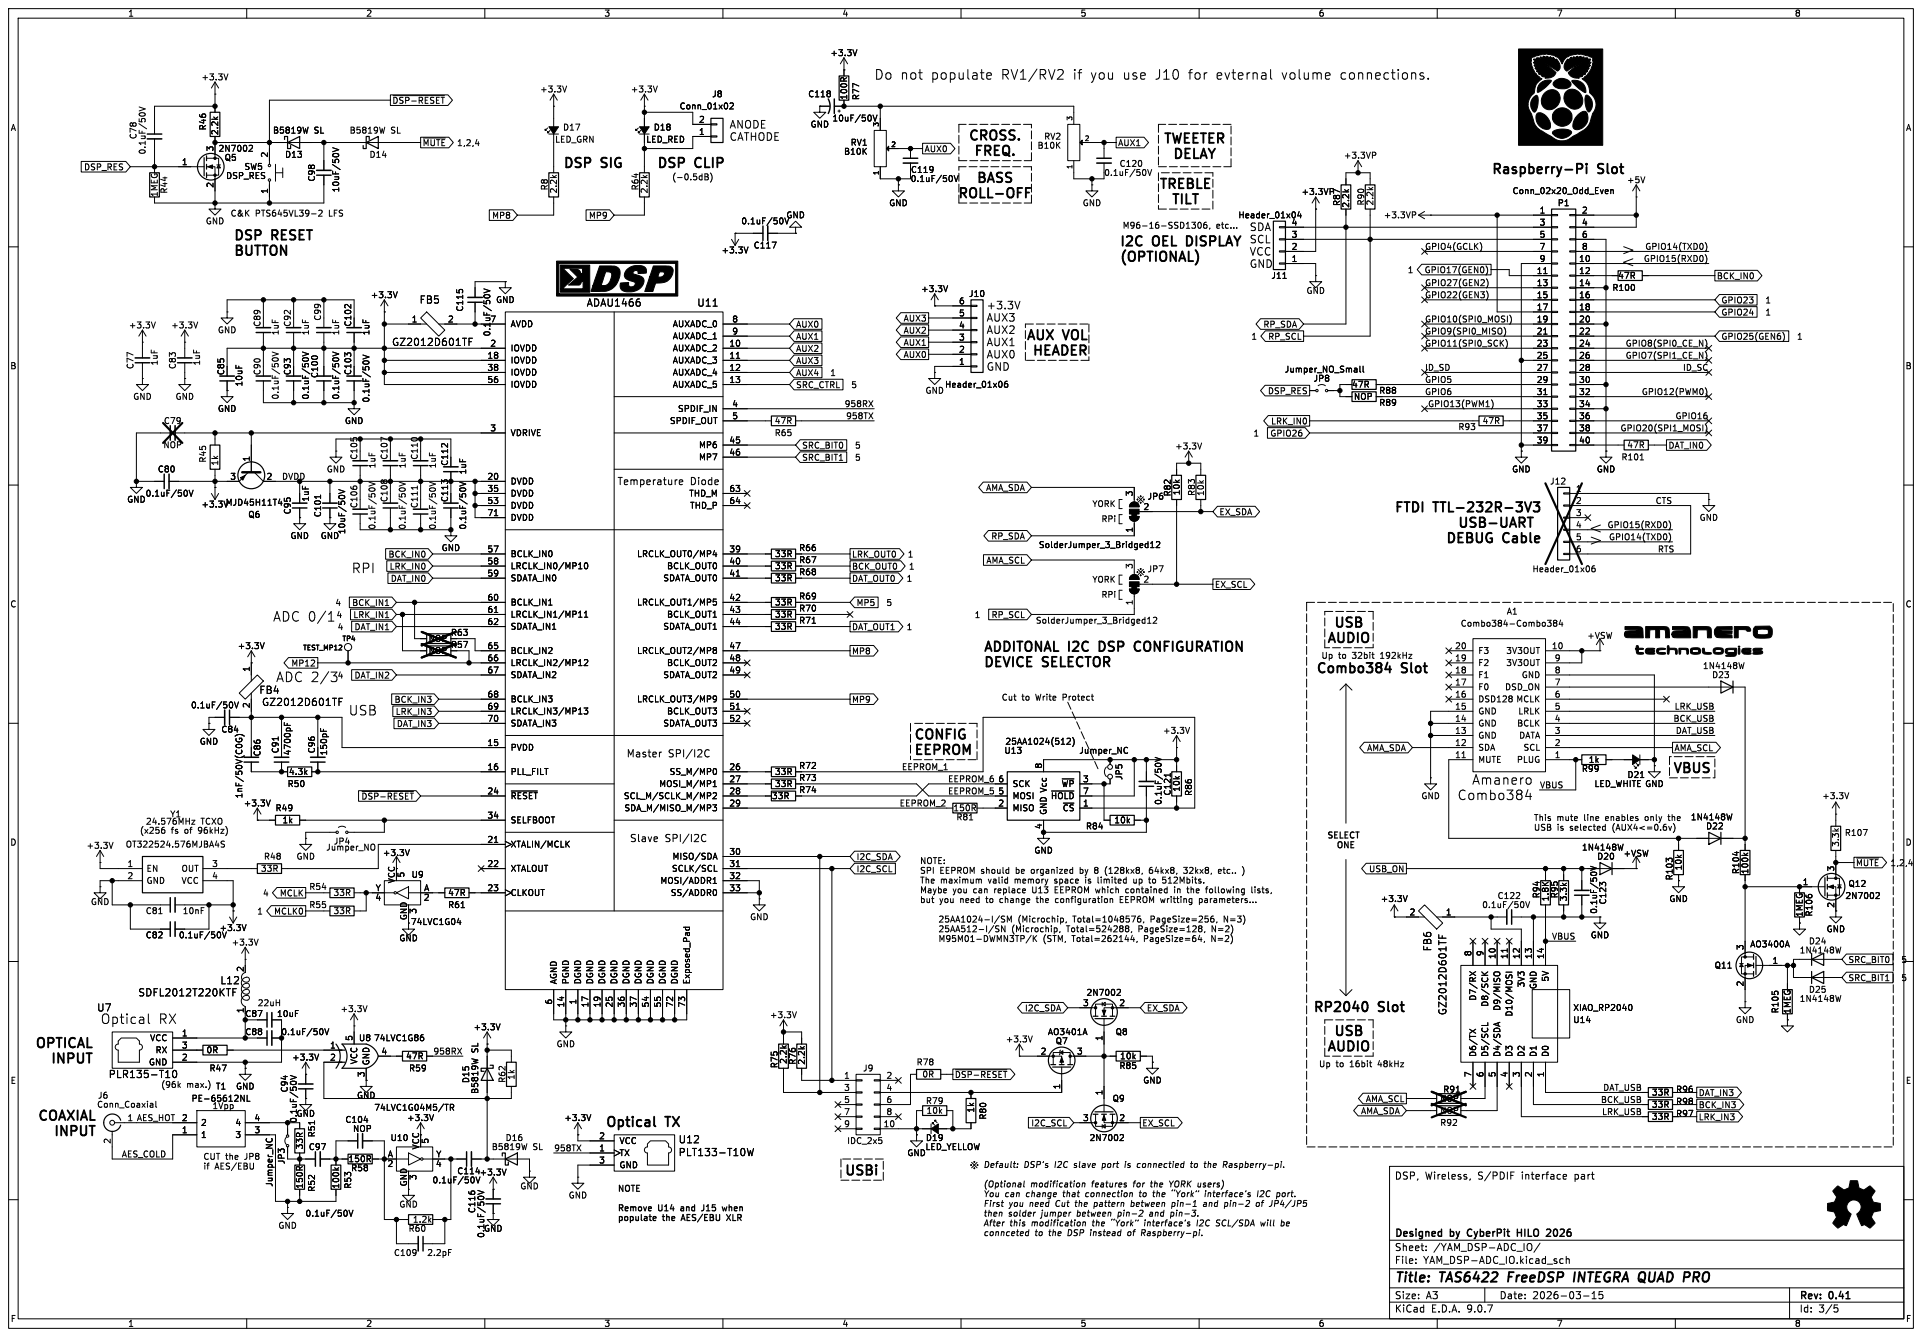
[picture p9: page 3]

Do not populate RV1/RV2 if you use J10 for evternal volume connections.

1 2D13 B5819W SL R46 2.2k C98 10uF/50V GND C951uF C101 10uF/50V GND GND C112 1uF C113 0.1uF/50V U13

1 DGND 17 DGND 19 DGND 25 DGND 36 DGND 37 DGND 54 DGND 55 DGND 72 Exposed_Pad 73 AUXADC_0 8 AUXADC_1 9 AUXADC_2 10 AUXADC_3 11 AUXADC_4 12 AUXADC_5 13 SPDIF_IN 4 SPDIF_OUT 5 MP6 45 MP7 46 THD_M 63 THD_P 64

Cut to Write Protect ADDITONAL I2C DSP CONFIGURATION
DEVICE SELECTOR

populate the AES/EBU XLR USB

~{WP}3 ~{HOLD}7 ~{CS}1 Vcc 8 GND

4 SCK 6 MOSI 5 MISO 2 GND

7 5V 14 GND 13 3V3 12 D10/MOSI 11 D9/MISO 10 D8/SCK

NOTE Remove U14 and J15 when

File: YAM_DSP-ADC_IO.kicad_sch Sheet: /YAM_DSP-ADC_IO/
Id: 3/5 Title: TAS6422 FreeDSP INTEGRA QUAD PRO

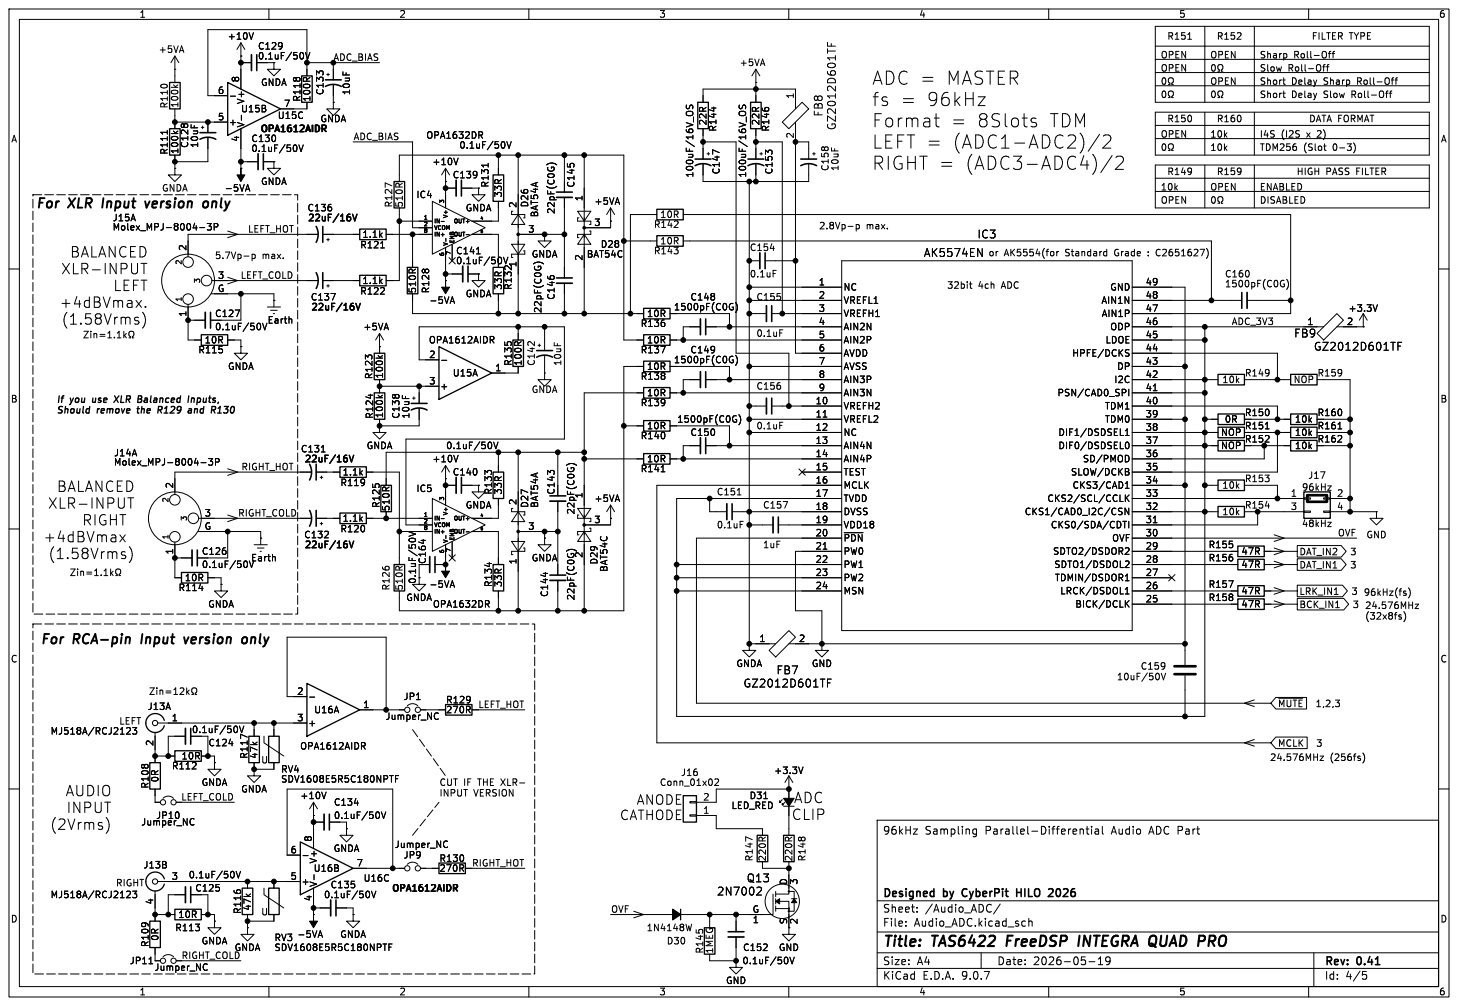
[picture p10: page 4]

For XLR Input version only

If you use XLR Balanced Inputs, Should remove the R129 and R130 BALANCED

For RCA-pin Input version only

CUT IF THE XLR-
INPUT VERSION

File: Audio_ADC.kicad_sch Sheet: /Audio_ADC/
Id: 4/5 Title: TAS6422 FreeDSP INTEGRA QUAD PRO

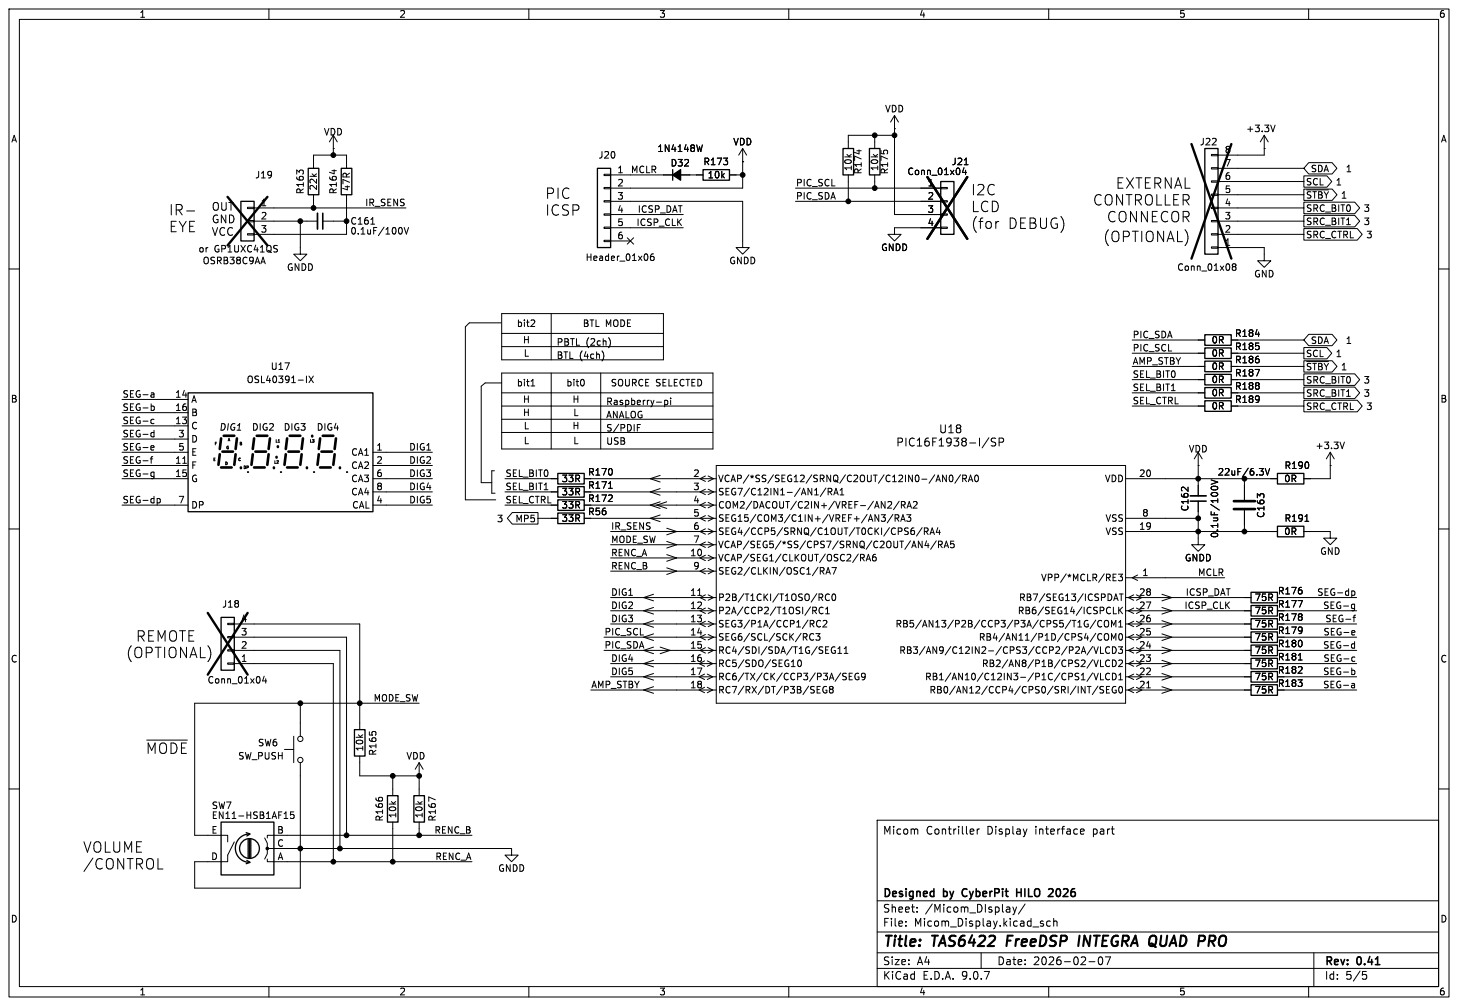
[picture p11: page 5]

SEG-e SEG-c SEG-b SEG-g

File: Micom_Display.kicad_sch Sheet: /Micom_DIsplay/
Id: 5/5 Title: TAS6422 FreeDSP INTEGRA QUAD PRO

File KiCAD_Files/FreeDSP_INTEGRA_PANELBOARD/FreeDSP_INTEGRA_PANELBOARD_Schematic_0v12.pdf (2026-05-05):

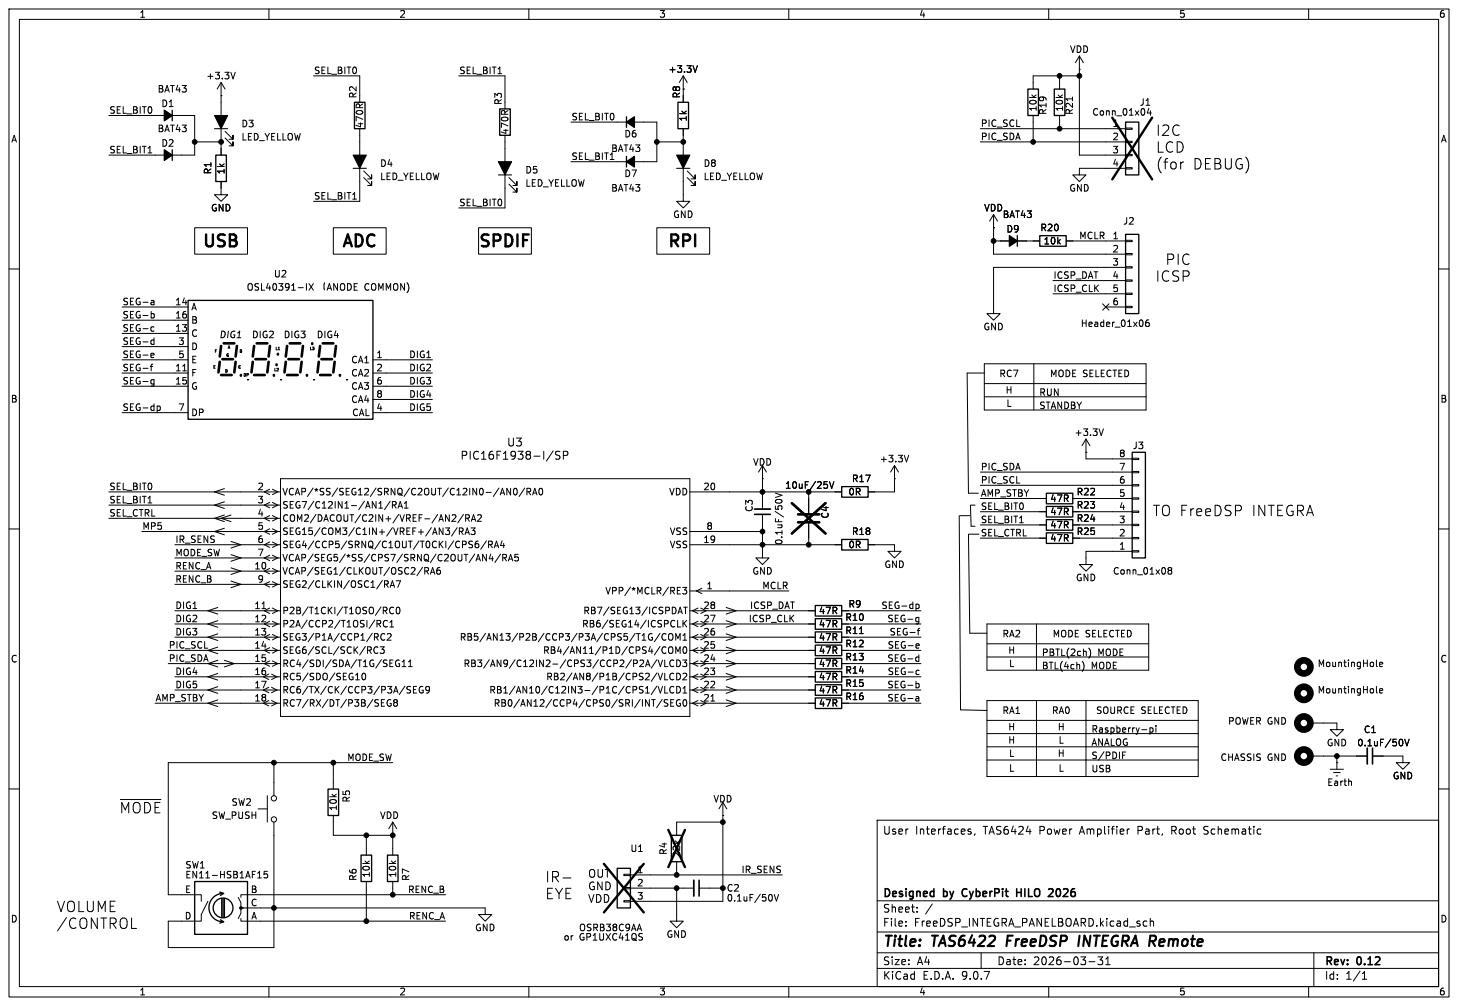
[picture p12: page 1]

0.1uF/50VGND Earth MountingHole GND MountingHole GND

Id: 1/1 Title: TAS6422 FreeDSP INTEGRA Remote

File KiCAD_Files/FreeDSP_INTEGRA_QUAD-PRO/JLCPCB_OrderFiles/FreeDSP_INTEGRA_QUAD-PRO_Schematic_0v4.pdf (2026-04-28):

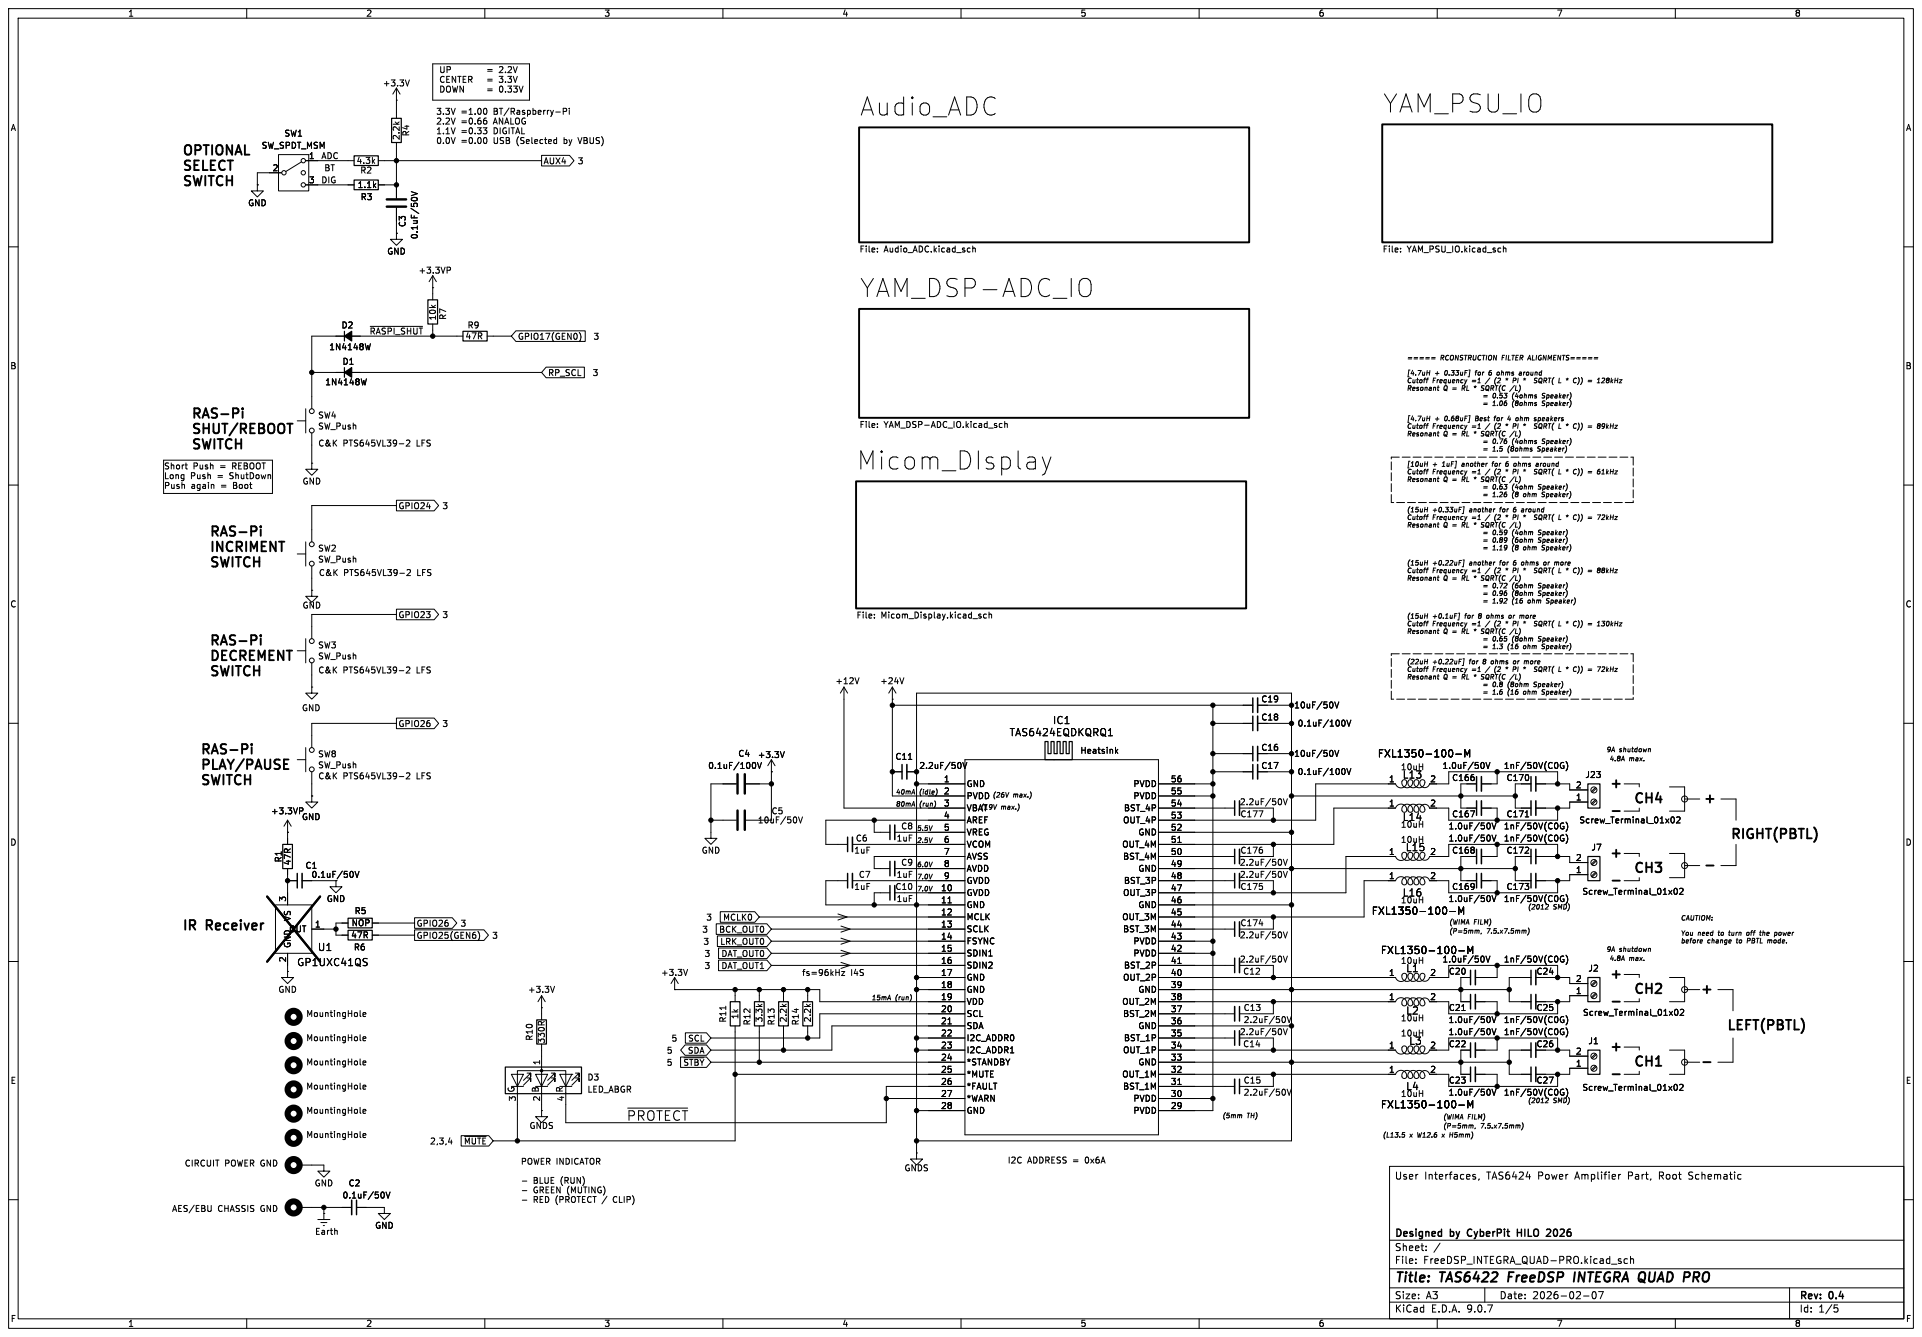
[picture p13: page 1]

BT ADC RAS-Pi
SELECT
SWITCH

SHUT/REBOOT
AES/EBU CHASSIS GND RAS-Pi
SW3 SW_Push R1 47R

Id: 1/5 Title: TAS6422 FreeDSP INTEGRA QUAD PRO

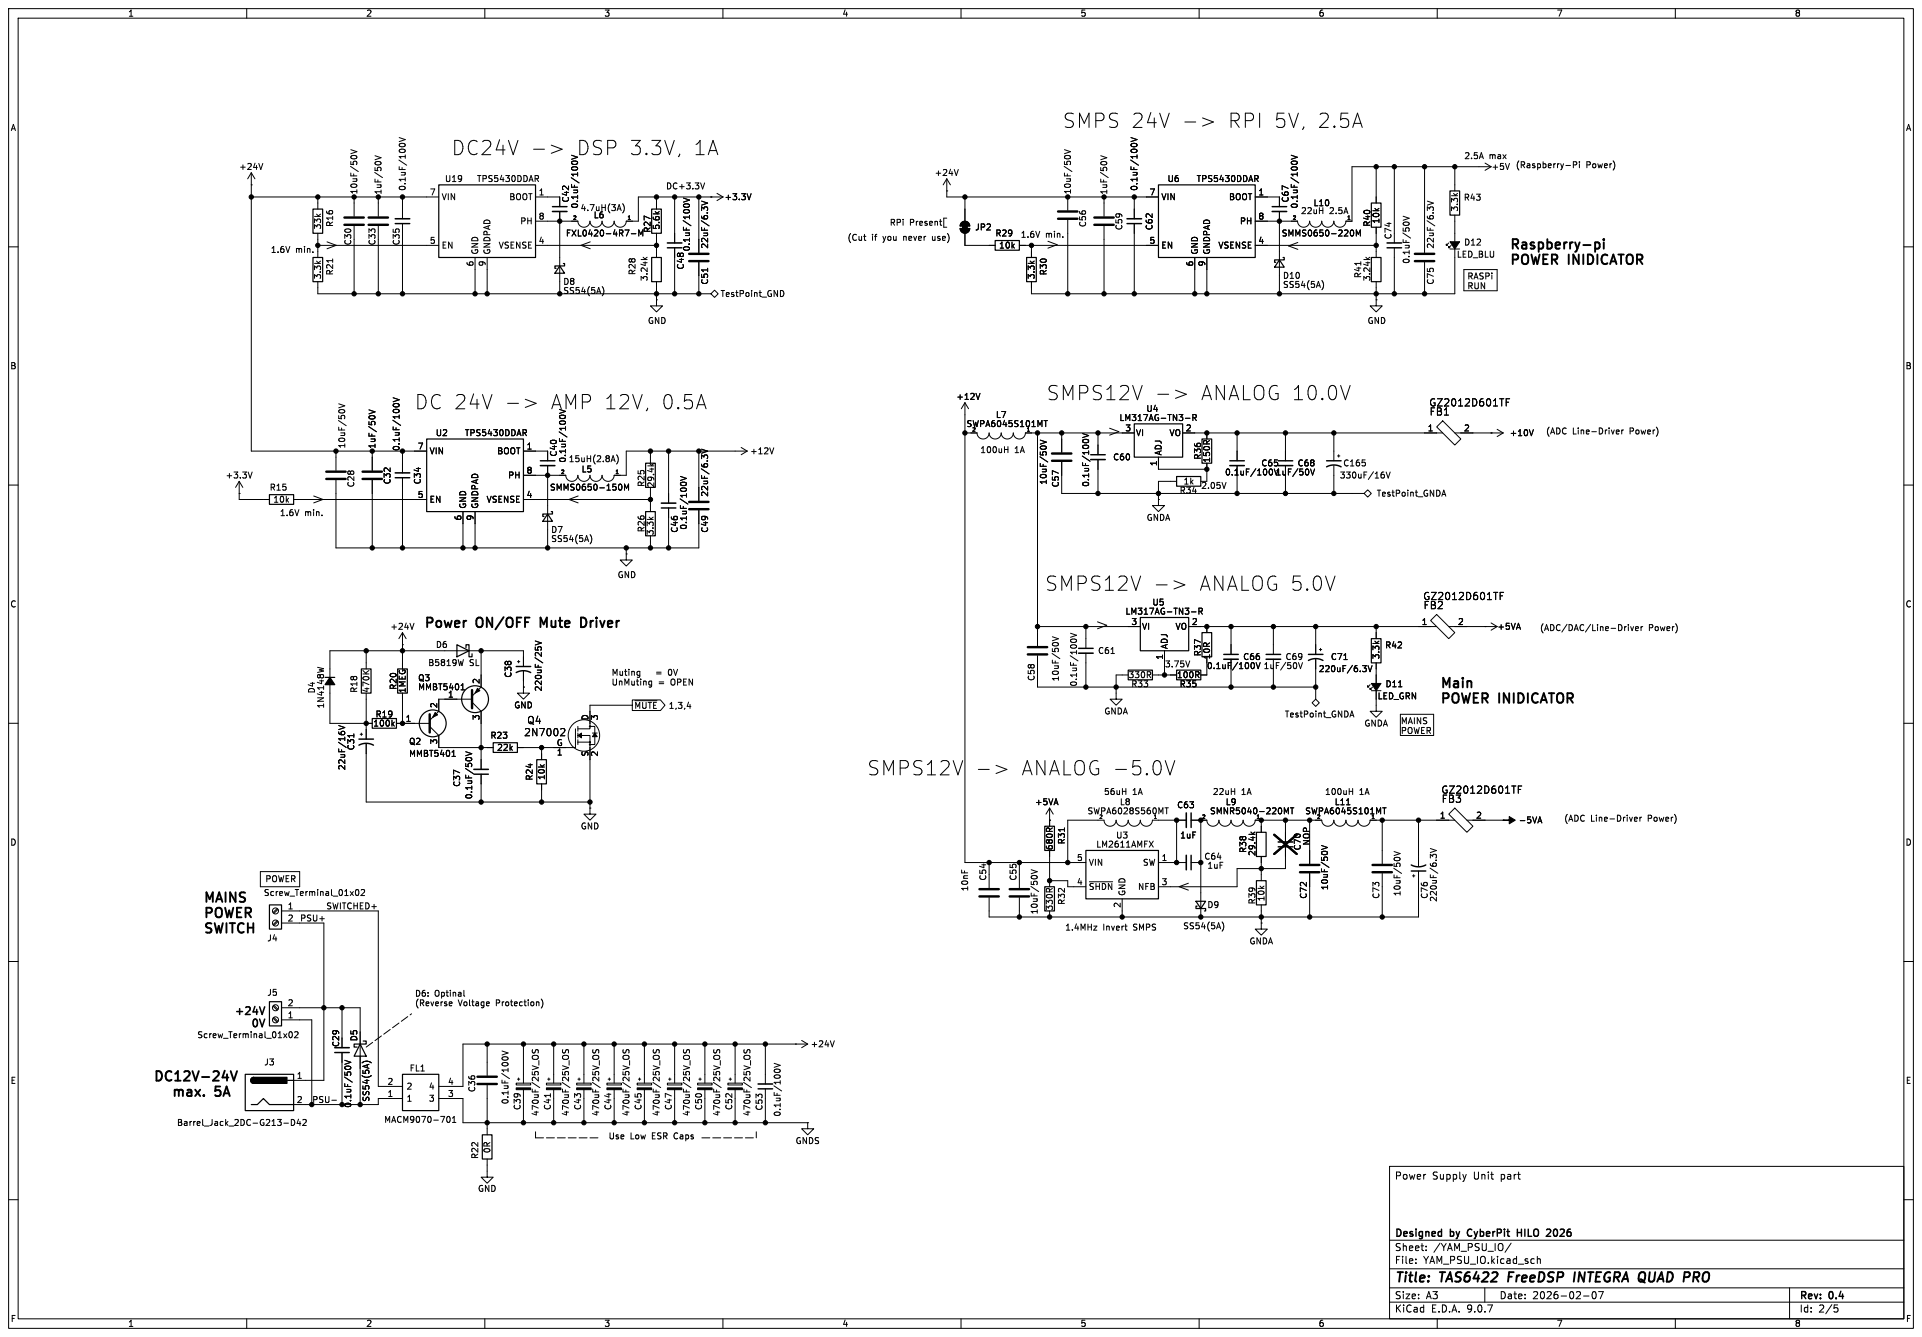
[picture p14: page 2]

Power ON/OFF Mute Driver

~{MUTE}1,3,4 SWITCHED+ PSU+PSU- POWER MAINS

Use Low ESR Caps

File: YAM_PSU_IO.kicad_sch Sheet: /YAM_PSU_IO/
Id: 2/5 Title: TAS6422 FreeDSP INTEGRA QUAD PRO

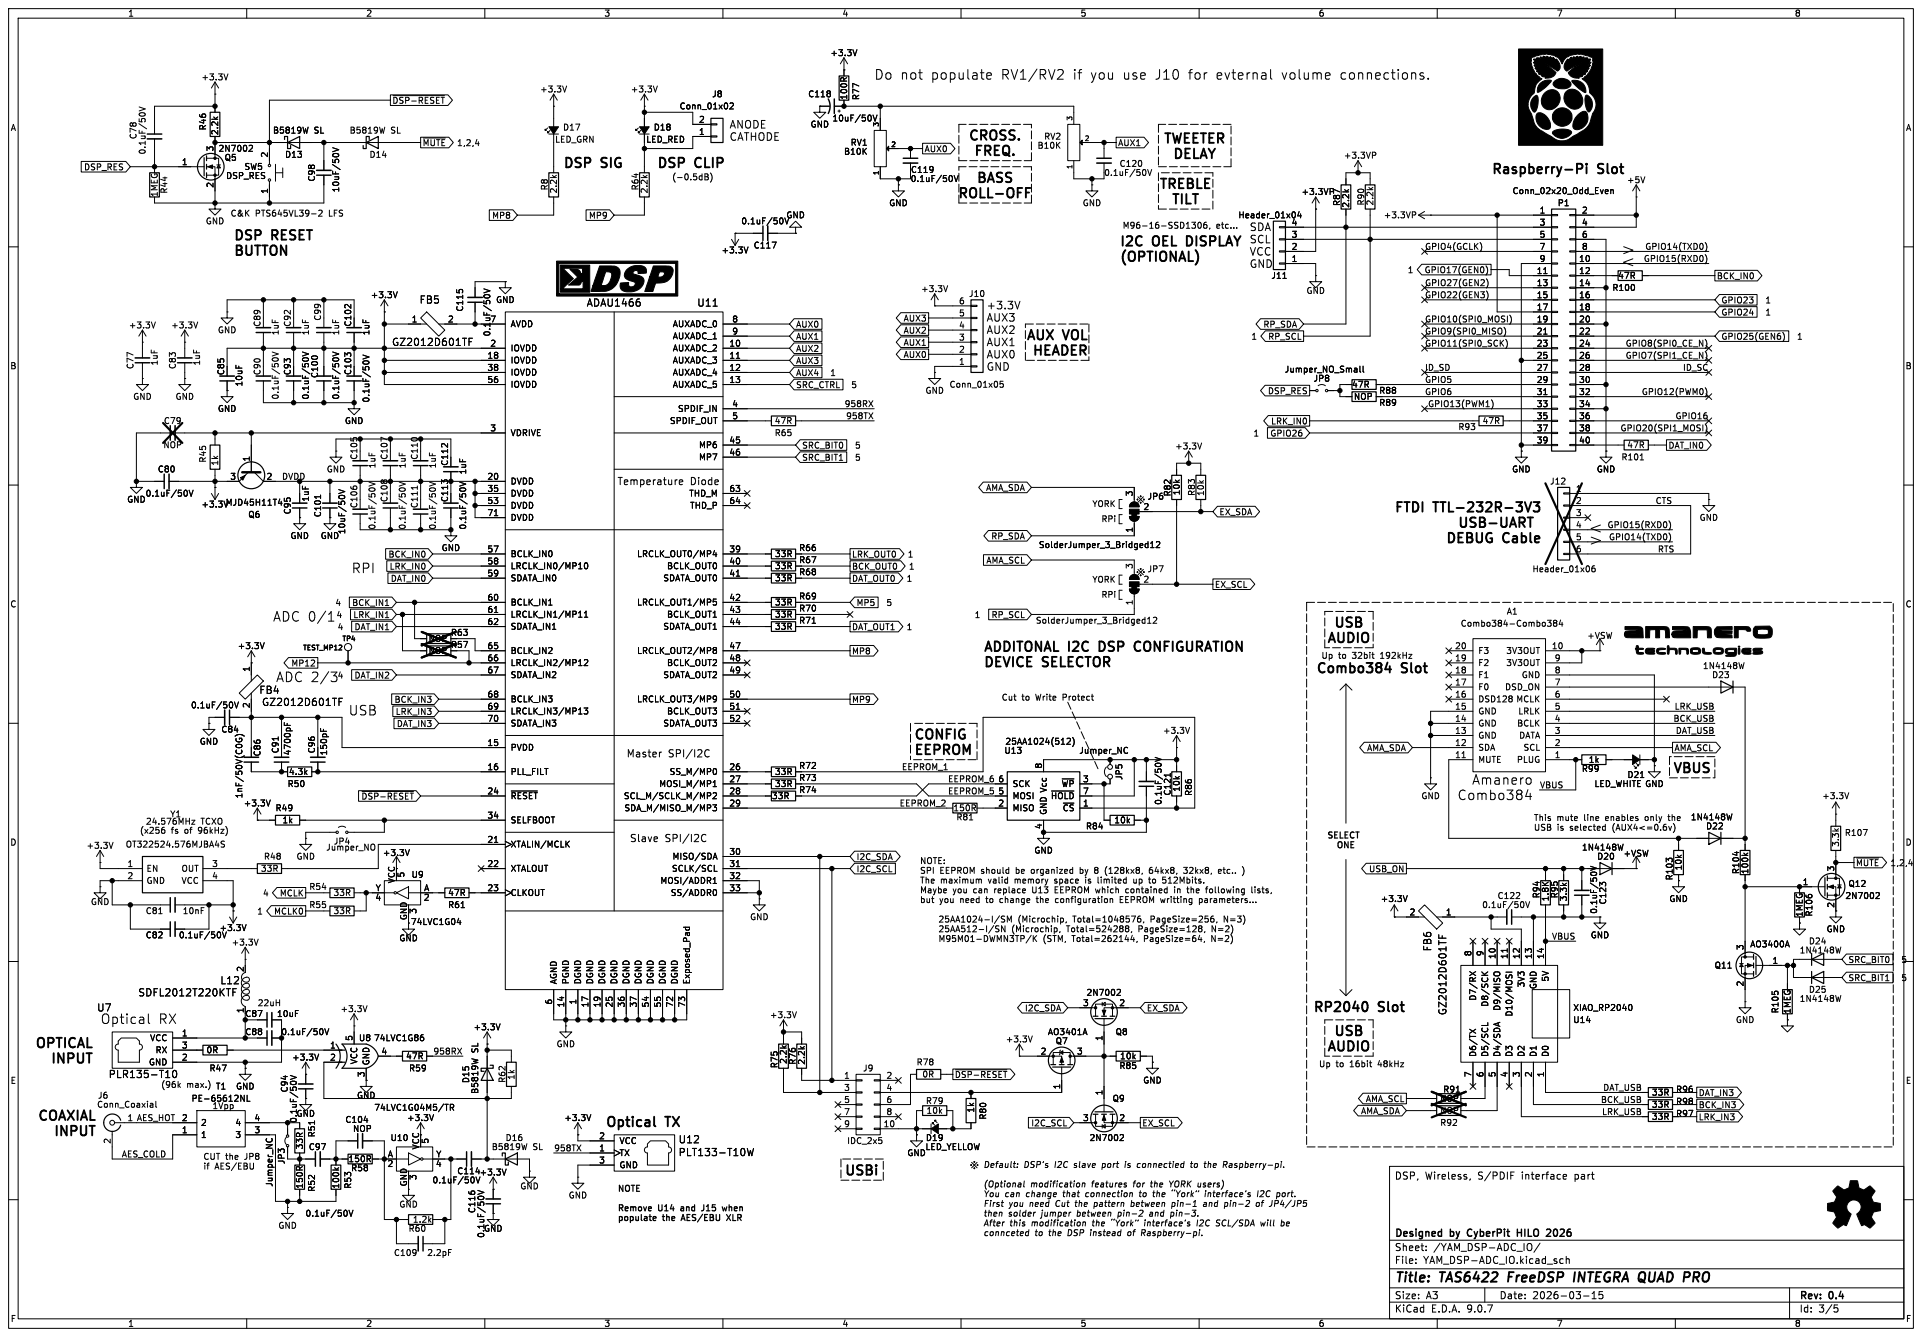
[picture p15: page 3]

Up to 16bit 48kHz Up to 32bit 192kHz TWEETER

1 2 SW5 DSP_RES D13 B5819W SL C92 1uF R46 2.2k +3.3V C78 0.1uF/50V C99 1uF D14 B5819W SL C98 10uF/50V GND C101 10uF/50V GND C951uF GND GNDC105 1uF C93 0.1uF/50V C119

þÿ ; RPi Do not populate RV1/RV2 if you use J10 for evternal volume connections.

1 2D13 B5819W SL R46 2.2k C98 10uF/50V C101 10uF/50V GND C951uF GND GND C112 1uF C113 0.1uF/50V GND

1 DGND 17 DGND 19 DGND 25 DGND 36 DGND 37 DGND 54 DGND 55 DGND 72 Exposed_Pad 73 AUXADC_0 8 AUXADC_1 9 AUXADC_2 10 AUXADC_3 11 AUXADC_4 12 AUXADC_5 13 SPDIF_IN 4 SPDIF_OUT 5 MP6 45 MP7 46 THD_M 63 THD_P 64

Cut to Write Protect ADDITONAL I2C DSP CONFIGURATION
DEVICE SELECTOR

~{WP}3 ~{HOLD}7 ~{CS}1 Vcc 8 GND

7 5V 14 GND 13 3V3 12 D10/MOSI 11 D9/MISO 10 D8/SCK

NOTE Remove U14 and J15 when

populate the AES/EBU XLR

File: YAM_DSP-ADC_IO.kicad_sch Sheet: /YAM_DSP-ADC_IO/
Id: 3/5 Title: TAS6422 FreeDSP INTEGRA QUAD PRO

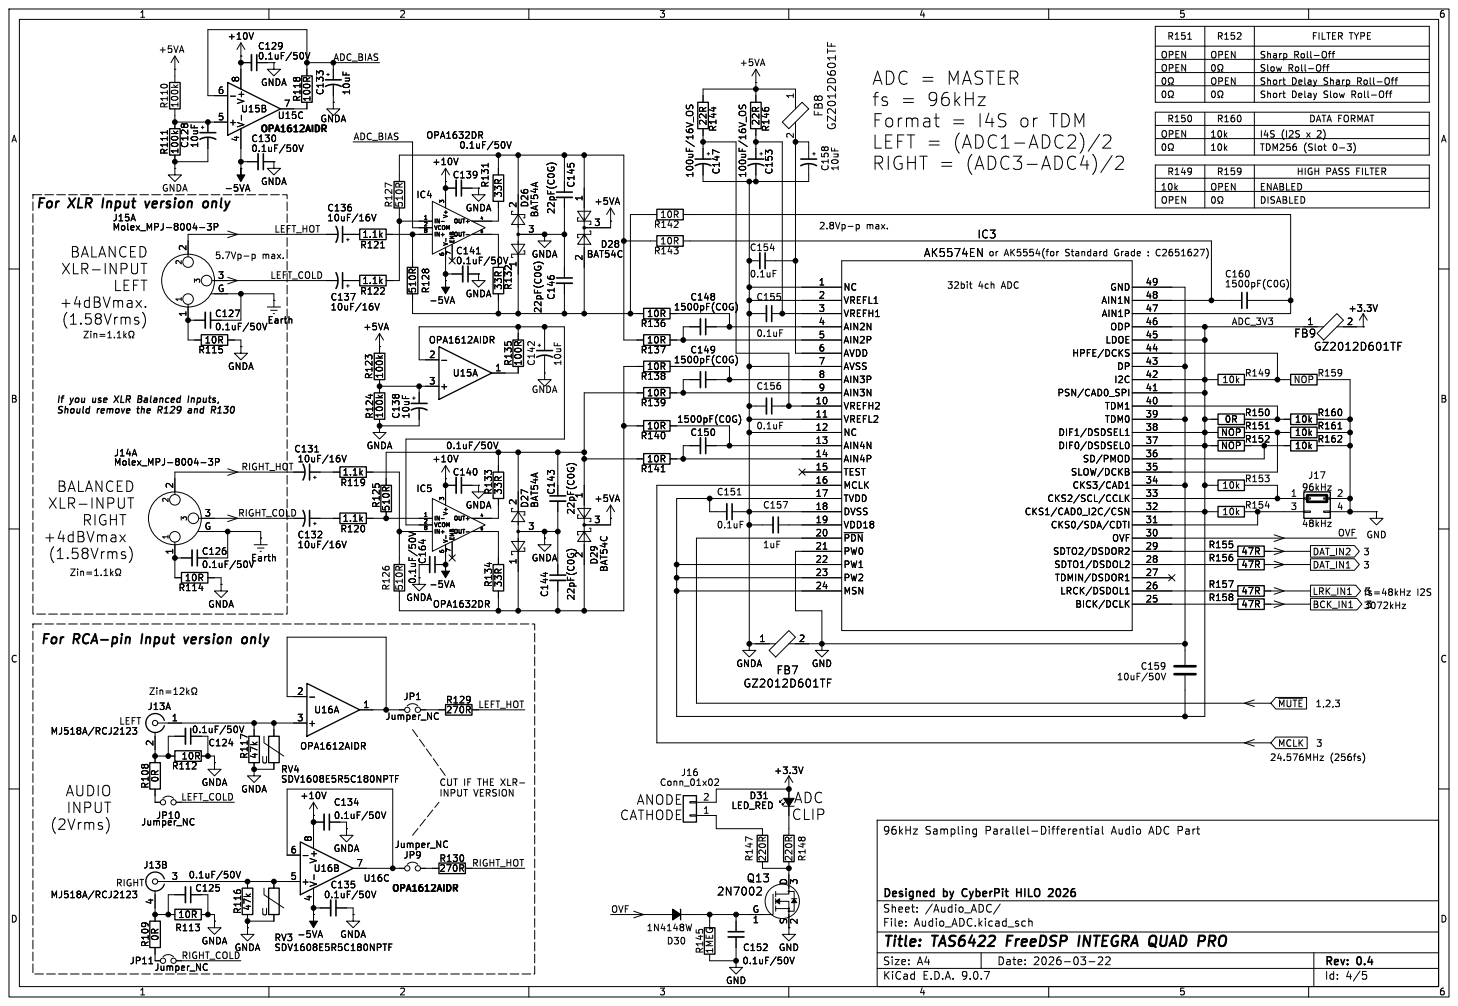
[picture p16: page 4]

For XLR Input version only

If you use XLR Balanced Inputs, Should remove the R129 and R130

For RCA-pin Input version only

File: Audio_ADC.kicad_sch Sheet: /Audio_ADC/
Id: 4/5 Title: TAS6422 FreeDSP INTEGRA QUAD PRO

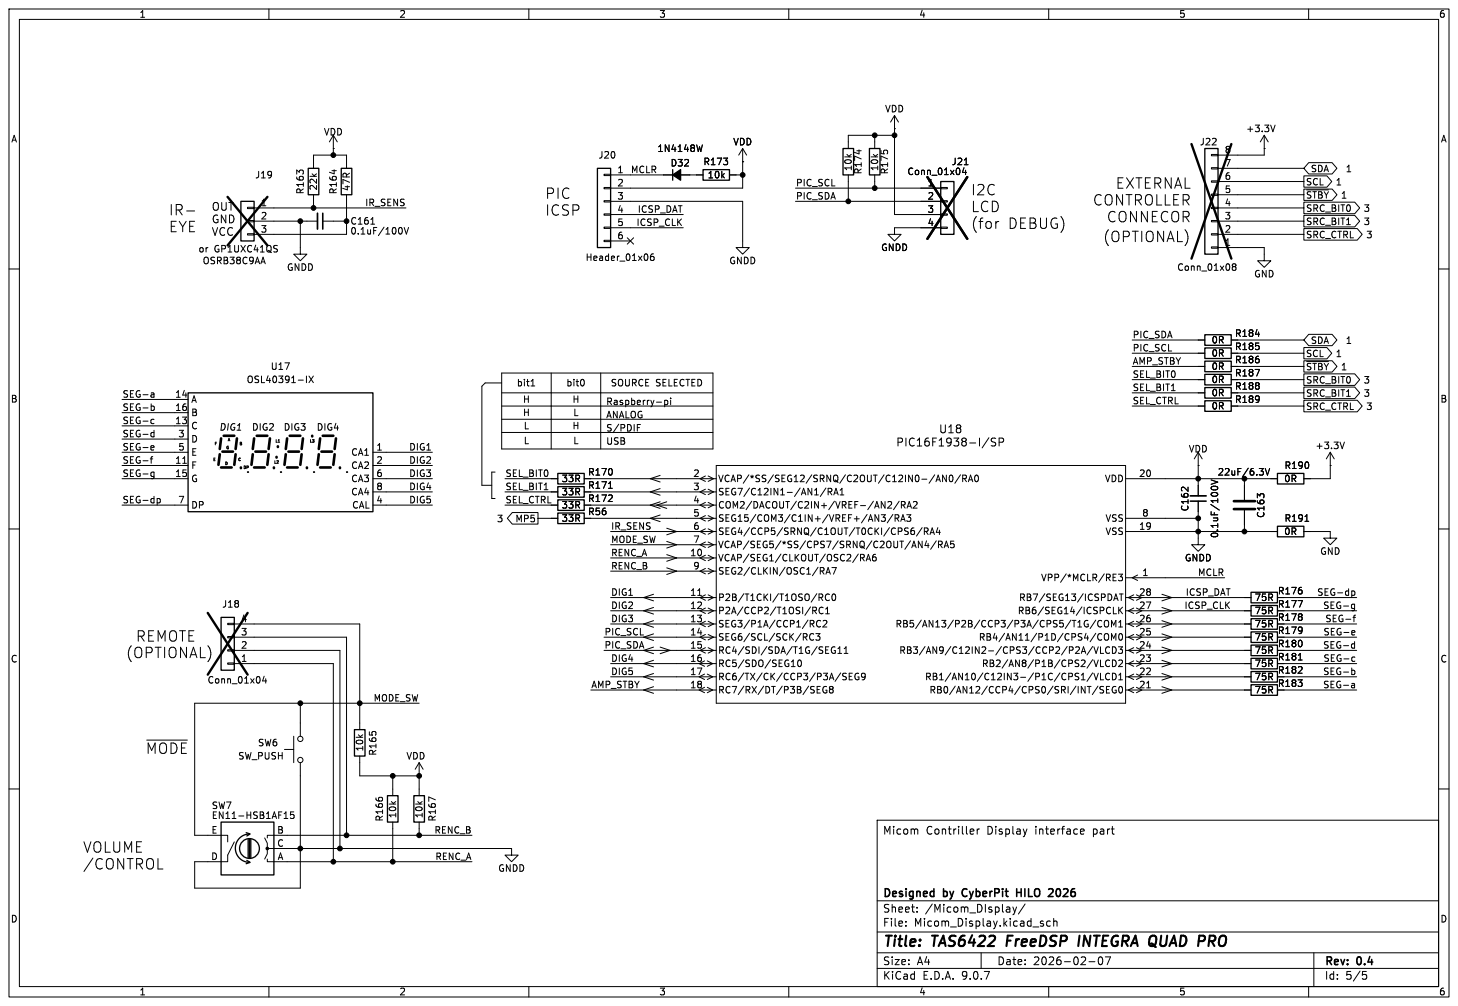
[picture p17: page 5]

File: Micom_Display.kicad_sch Sheet: /Micom_DIsplay/
Id: 5/5 Title: TAS6422 FreeDSP INTEGRA QUAD PRO

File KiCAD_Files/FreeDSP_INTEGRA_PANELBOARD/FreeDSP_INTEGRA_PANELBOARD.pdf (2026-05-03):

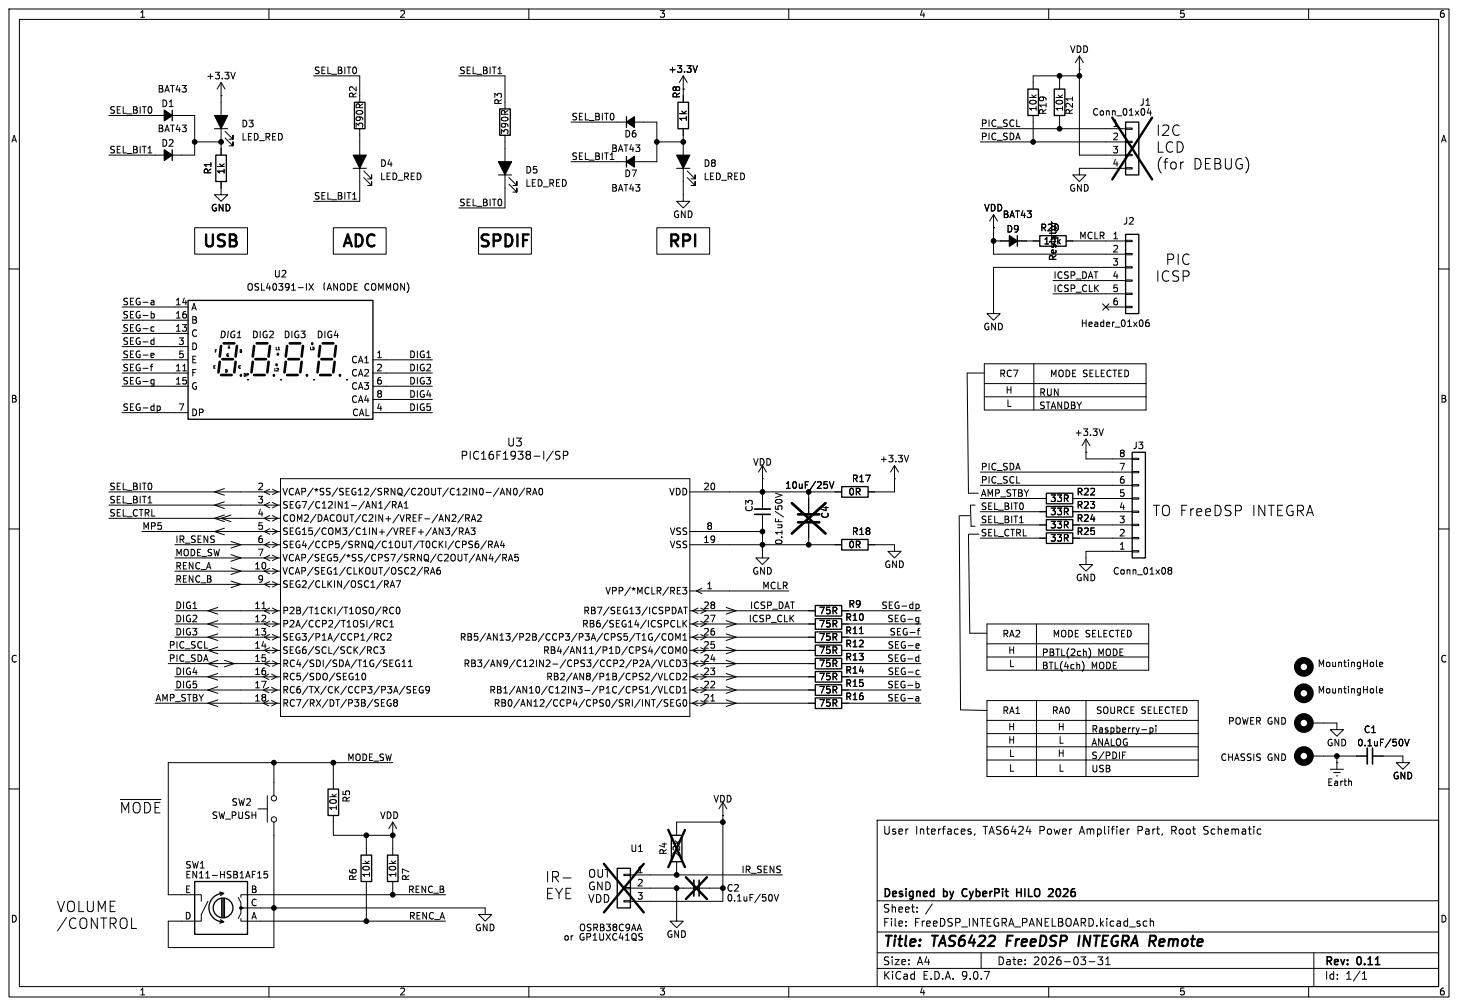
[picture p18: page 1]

Id: 1/1 Title: TAS6422 FreeDSP INTEGRA Remote


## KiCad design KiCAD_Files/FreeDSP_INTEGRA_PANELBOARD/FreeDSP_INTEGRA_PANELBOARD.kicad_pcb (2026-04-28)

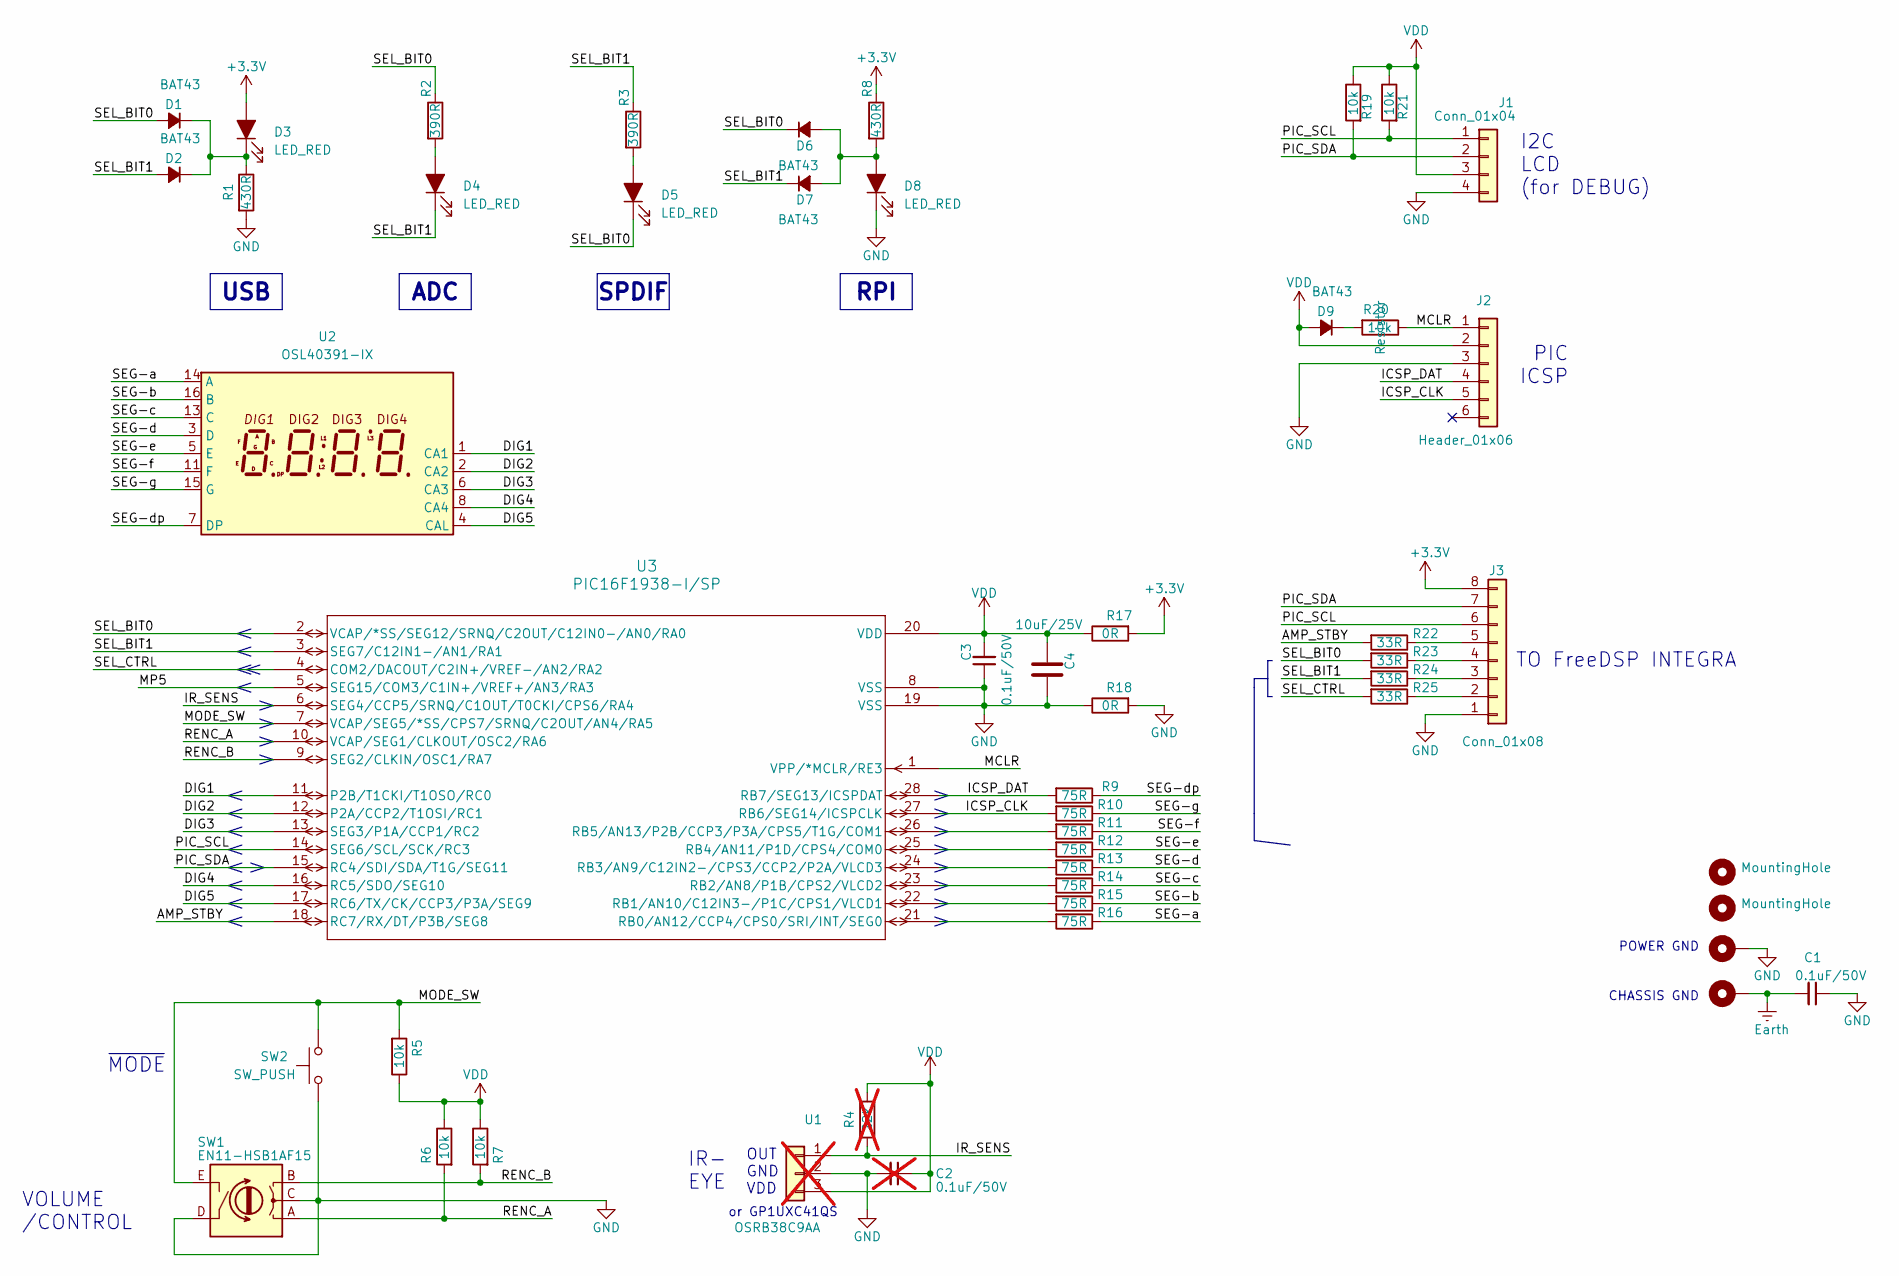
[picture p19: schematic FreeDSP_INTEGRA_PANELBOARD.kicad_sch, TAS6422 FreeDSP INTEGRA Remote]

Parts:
C1, C3: 0.1uF/50V; C_Disc_D4.3mm_W1.9mm_P5.00mm
C2: 0.1uF/50V; C_Disc_D4.3mm_W1.9mm_P5.00mm; not fitted
C4: 10uF/25V; C_0805_2012Metric
D1, D2, D6, D7, D9: BAT43; D_A-405_P7.62mm_Horizontal
D3, D4, D5, D8: LED_RED; LED_D3.0mm_FlatTop
HM1: MountingHole_Pad_via; MountingHole_3.2mm_M3_ISO7380_Pad_TopBottom
J1: Conn_01x04; PinHeader_1x04_P2.54mm_Vertical
J2: Header_01x06; PinHeader_1x06_P2.54mm_Vertical
J3: Conn_01x08; PinHeader_1x08_P2.54mm_Vertical
MH1, MH2: MountingHole; MountingHole_3.2mm_M3_DIN965_Pad_TopBottom
MH3: M3; MountingHole_3.2mm_M3_Pad_Via
R1, R8: 430R; R_Axial_DIN0204_L3.6mm_D1.6mm_P5.08mm_Horizontal
R2, R3: 390R; R_Axial_DIN0204_L3.6mm_D1.6mm_P5.08mm_Horizontal
R4: 22k; R_Axial_DIN0204_L3.6mm_D1.6mm_P5.08mm_Horizontal; not fitted
R5, R6, R7, R19, R20, R21: 10k; R_Axial_DIN0204_L3.6mm_D1.6mm_P5.08mm_Horizontal
R9, R10, R11, R12, R13, R14, R15, R16: 75R; R_Axial_DIN0204_L3.6mm_D1.6mm_P5.08mm_Horizontal
R17, R18: 0R; R_Axial_DIN0204_L3.6mm_D1.6mm_P5.08mm_Horizontal
R22, R23, R24, R25: 33R; R_Axial_DIN0204_L3.6mm_D1.6mm_P5.08mm_Horizontal
SW1: EN11-HSB1AF15; RotaryEncoder_TT-Ele_EN11-HSB1AF15
SW2: SW_PUSH; SW_PUSH_6mm_H4.3mm
U1: OSRB38C9AA; IR_Receiver_TSOP38238; not fitted
U2: OSL40391-IX; LTC-4627Jx
U3: PIC16F1938-I/SP; PIC16F1938-X&slash_SP_MCH(Socket)

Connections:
+3.3V: D3.2 (A), J3.8, R8.1, R17.2
/AMP_STBY: R22.2, U3.18 (RC7/RX/DT/P3B/SEG8)
/DIG1: U2.1 (CA1), U3.11 (P2B/T1CKI/T1OSO/RC0)
/DIG2: U2.2 (CA2), U3.12 (P2A/CCP2/T1OSI/RC1)
/DIG3: U2.6 (CA3), U3.13 (SEG3/P1A/CCP1/RC2)
/DIG4: U2.8 (CA4), U3.16 (RC5/SDO/SEG10)
/DIG5: U2.4 (CAL), U3.17 (RC6/TX/CK/CCP3/P3A/SEG9)
/ICSP_CLK: J2.5, R10.2, U3.27 (RB6/SEG14/ICSPCLK)
/ICSP_DAT: J2.4, R9.2, U3.28 (RB7/SEG13/ICSPDAT)
/IR_SENS: R4.2, U1.1, U3.6 (SEG4/CCP5/SRNQ/C1OUT/T0CKI/CPS6/RA4)
/MCLR: J2.1, R20.1, U3.1 (VPP/*MCLR/RE3)
/MODE_SW: R5.2, SW1.E, SW2.2, U3.7 (VCAP/SEG5/*SS/CPS7/SRNQ/C2OUT/AN4/RA5)
/MP5: U3.5 (SEG15/COM3/C1IN+/VREF+/AN3/RA3)
/PIC_SCL: J1.1, J3.6, R21.2, U3.14 (SEG6/SCL/SCK/RC3)
/PIC_SDA: J1.2, J3.7, R19.2, U3.15 (RC4/SDI/SDA/T1G/SEG11)
/RENC_A: R6.2, SW1.A, U3.10 (VCAP/SEG1/CLKOUT/OSC2/RA6)
/RENC_B: R7.2, SW1.B, U3.9 (SEG2/CLKIN/OSC1/RA7)
/SEG-a: R16.1, U2.14 (A)
/SEG-b: R15.1, U2.16 (B)
/SEG-c: R14.1, U2.13 (C)
/SEG-d: R13.1, U2.3 (D)
/SEG-dp: R9.1, U2.7 (DP)
/SEG-e: R12.1, U2.5 (E)
/SEG-f: R11.1, U2.11 (F)
/SEG-g: R10.1, U2.15 (G)
/SEL_BIT0: D1.2 (A), D5.1 (K), D6.1 (K), R2.1, R23.2, U3.2 (VCAP/*SS/SEG12/SRNQ/C2OUT/C12IN0-/AN0/R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)
/SEL_BIT1: D2.2 (A), D4.1 (K), D7.1 (K), R3.1, R24.2, U3.3 (SEG7/C12IN1-/AN1/RA1)
/SEL_CTRL: R25.2, U3.4 (COM2/DACOUT/C2IN+/VREF-/AN2/RA2)
Earth: C1.2, MH3.1
GND: C1.1, C2.2, C3.1, C4.2, D8.1 (K), HM1.1, J1.4, J2.3, J3.1, R1.2, R18.1, R18.2, SW1.C, SW1.D, SW2.1, U1.2, U3.8 (VSS), U3.19 (VSS)
unnamed: D1.1 (K), D2.1 (K), D3.1 (K), R1.1
unnamed: D4.2 (A), R2.2
unnamed: D5.2 (A), R3.2
unnamed: D6.2 (A), D7.2 (A), D8.2 (A), R8.2
unnamed: D9.1 (K), R20.2
unnamed: J3.2, R25.1
unnamed: J3.3, R24.1
unnamed: J3.4, R23.1
unnamed: J3.5, R22.1
unnamed: R16.2, U3.21 (RB0/AN12/CCP4/CPS0/SRI/INT/SEG0)
unnamed: R15.2, U3.22 (RB1/AN10/C12IN3-/P1C/CPS1/VLCD1)
unnamed: R14.2, U3.23 (RB2/AN8/P1B/CPS2/VLCD2)
unnamed: R13.2, U3.24 (RB3/AN9/C12IN2-/CPS3/CCP2/P2A/VLCD3)
unnamed: R12.2, U3.25 (RB4/AN11/P1D/CPS4/COM0)
unnamed: R11.2, U3.26 (RB5/AN13/P2B/CCP3/P3A/CPS5/T1G/COM1)
VDD: C2.1, C3.2, C4.1, D9.2 (A), J1.3, J2.2, R4.1, R5.1, R6.1, R7.1, R17.1, R19.1, R21.1, U1.3, U3.20 (VDD)

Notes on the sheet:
~{MODE}
OUT GND VDD
IR- EYE
CHASSIS GND
PIC ICSP
I2C LCD (for DEBUG)
TO FreeDSP INTEGRA
VOLUME /CONTROL
POWER GND
or GP1UXC41QS
USB
SPDIF
ADC
RPI

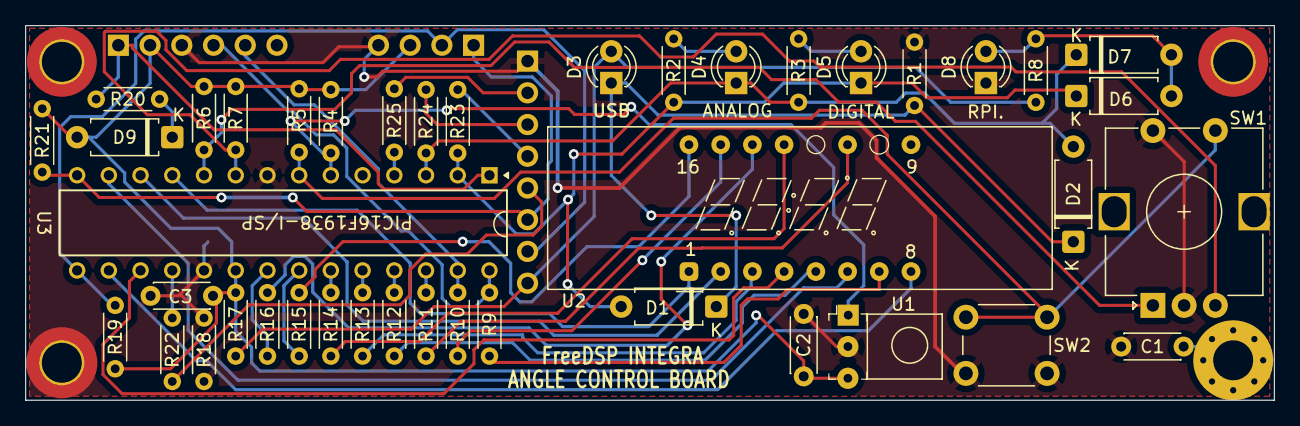
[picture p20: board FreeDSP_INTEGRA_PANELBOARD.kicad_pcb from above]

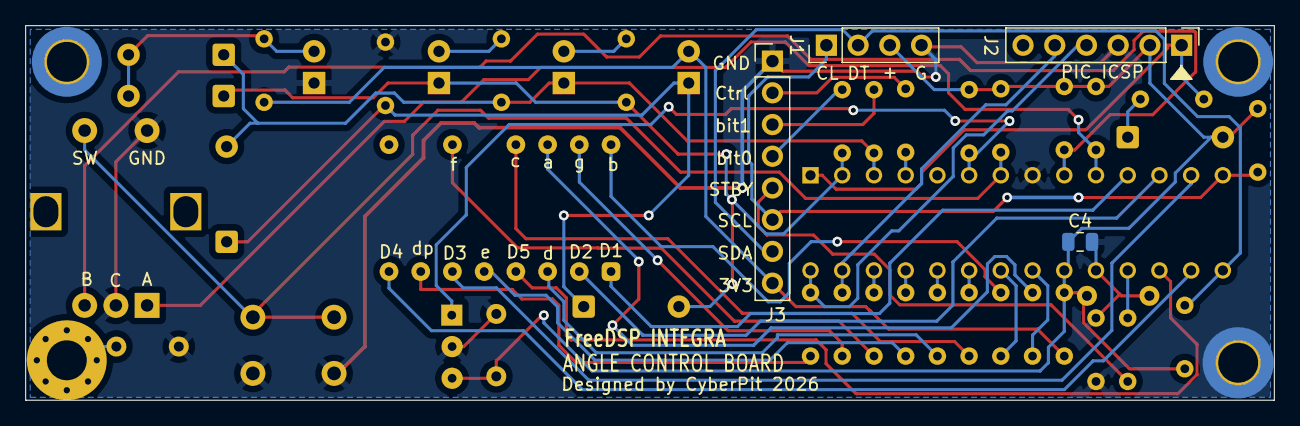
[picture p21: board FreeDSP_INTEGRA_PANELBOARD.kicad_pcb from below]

Board: 2 copper layers, 100.0 x 30.0 mm, 50 parts (4 on the bottom side), 45 nets.

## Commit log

2026-04-28 Initial Release
    [Audio_ADC.kicad_sch, FreeDSP_INTEGRA_PANELBOARD.dsn, FreeDSP_INTEGRA_PANELBOARD.kicad_pcb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]
2026-04-28 Low cost AK5552 version
    [Audio_ADC.kicad_sch, FreeDSP_INTEGRA-QUAD-PRO_BOM1.xlsx, FreeDSP_INTEGRA_QUAD-PRO_PartsListALL.xlsx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]
2026-05-03 Add files via upload
    Fix some values.
    [FreeDSP_INTEGRA_PANELBOARD.kicad_sch, FreeDSP_INTEGRA_PANELBOARD_PartsList.xlsx]
2026-05-05 Parts value changed
    [FreeDSP_INTEGRA_PANELBOARD.kicad_sch, FreeDSP_INTEGRA_PANELBOARD_PartsList.xlsx]
